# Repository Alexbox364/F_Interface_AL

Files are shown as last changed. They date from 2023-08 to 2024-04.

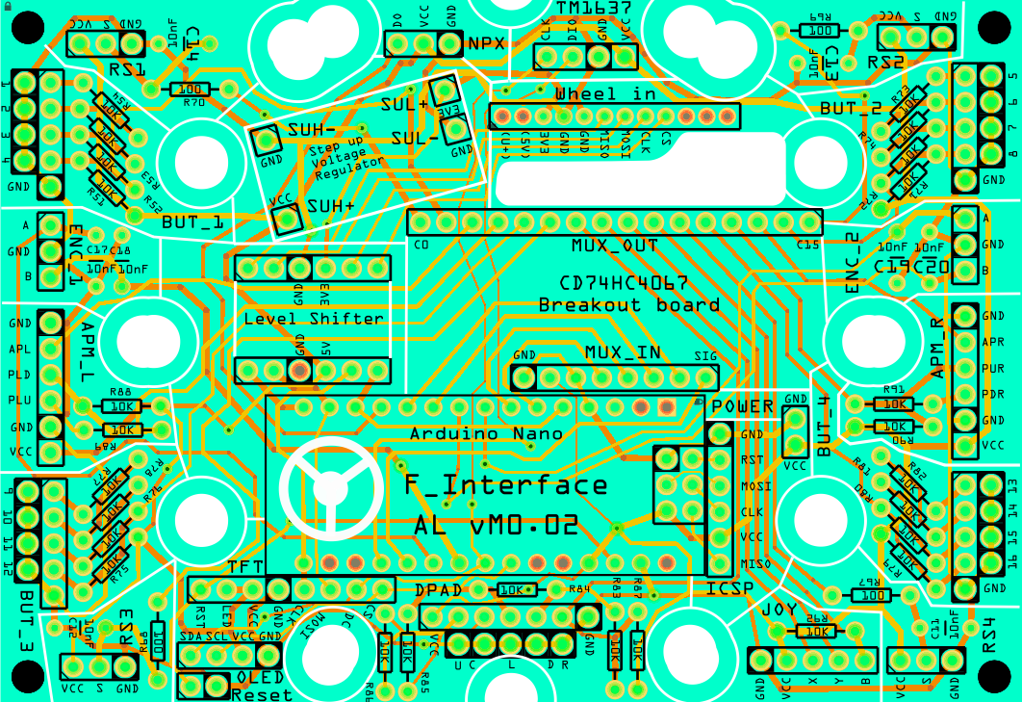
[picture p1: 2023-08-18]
F_Interface_AL_Hardware_v0.02/F_Interface_AL_Hardware_v0.02_circuit imprimé.png

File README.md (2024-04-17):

# F_Interface_AL Project v0.06
##DIY steering wheel and button bow project

You want to build your own DIY Fanatec base compatible Steering Wheel? You're at the right place :-)

Welcome to the F_interface project. 

Purpose of this project is to bring a versatile platform to build DIY steering wheels intended to work with Fanatec simracing bases. 



Fanatec ecosystem is great for simracing, but when it comes to integrate custom DIY wheel to enrich your experience, possibilities are limited. 

You can use the Podium hub to hook up a rim and few buttons but you don’t have much more possibilities. 

The F_interface offers you the opportunity to build a custom DIY wheel with a variety of combinations including :

- Up to 24 push buttons
- Up to 2 rotary encoders
- Up to 4 rotary switches
- Advance paddle modules
- TM1637 segmented displays
- OLED displays
- TFT LCD display
- Individually addressable RGB LEDs

This project brings you both a hardware and software platform to help you build your dream DIY wheel. 

It is build on using the SPI protocol from Fanatec to communicate between the wheel and the base. This way, you don’t need any cable or wireless communication between the wheel and the base, everything goes through the pins in the center of the Fanatec QR system.

This work is based on previous work from [Darknao](https://github.com/darknao/btClubSportWheel) and [Ishachar](https://github.com/lshachar/Arduino_Fanatec_Wheel) who brought public the base of the SPI communication between the Fanatec base and the wheels.

The SPI protocol is not yet fully understood. So what is currently feasible is : 
- use up to 24 buttons (including D-pad / rotary encoders / rotary switches)  
- use 2 axis for clutch / brake / acceleration
- get 9 status LEDs
- get 7 segment display information
—> tu sum it up, all features of wheels like Porsche 918 RSR, BMW GT2 v1...

What is currently not possible :
- get RGB Led information
- get enriched information displayed en latest OLED displays like lap time, tire pressure,…
- more buttons 
—> to sum it up, extended features brought by Maclaren GT3 v2 wheel, formula v2.5, Porsche endurance are not accessible yet, unless we better understand SPI protocol used by these wheels and by the data port.
BUT, there is a hope to integrate these feature via bluetooth using a Arduino nano ESP 32 and Simhub in future development to integrate TFT LCD screens, if your project really needs it. 

# The Hardware
The New F_interface is available in multiple form factors to suit your needs in terms of wheel setup. All board versions were designed using Fritzing, all source files are available in the repo. It is designed to be easily soldered by anyone using as few various components as possible and using only cheap and available components. It’s versatile, in the way you can only solder group of components that interest you for your build, especially if you want more rotary switches or more buttons,…

All details about the board can be found in the F_Interface_HW file. 

On the hardware side, you now have the choice between various versions depending on your needs. They vary in terms of sizes and inputs/output capabilities. They though all use the same base schematic to establish the link with the Fanatec base.

A presentation of the range is available below. The main hardware platform which is described if the original one beeing the FULL_NANO version. 

- A smallest form factor PCB based on an ATMEGA328P microcontroller just to unlock the force feedback for advanced users : ATMEGA328P_NO_HEADER
- A smallest form factor PCB based on an ATMEGA328P microcontroller just to unlock the force feedback + a few buttons for advanced user : ATMEGA328P_WITH_HEADER
- A small form factor PCB based on an arduino nano just to unlock the force feedback : NANO_NO_HEADER
- A small form factor PCB based on an arduino nano just to unlock the force feedback + a few buttons : NANO_WITH_HEADER
- A small form factor PCB based on an arduino PRO MICRO just to unlock the force feedback + a few buttons : PROMICRO_WITH_HEADER
- A podium hub form factor PCB based on an arduino nano with full features (buttons, rotary encoder, rotary switches) : FULL_NANO
- A podium hub form factor PCB based on an arduino PRO MICRO with full features (buttons, rotary encoder, rotary switches) : FULL_PROMICRO
- A button box wich is not intended to work with a Fanatec wheel base but which is very close in terms of I/Os.
















# Force feedback unlocker

Work from user Lele1494 is shared in the repo in the folder FFB unlocker_Lele1494.

It features a Fanatec force feedback unlocker in the shape of a small dongle. 

311509914-fe021610-d0ed-4bec-9fa5-f2b88aa8f5ab
313604595-764e521d-4c99-446e-8980-a8b3b699f9a5
313604620-f500a8e4-6ad1-47dd-8eb8-25f93431ef64

# Old presentation for legacy : F_Interface_AL Project v0.02

You want to build your own DIY Fanatec base compatible Steering Wheel? You're at the right place :-)

Welcome to the F_interface project. 

Purpose of this project is to bring a versatile platform to build DIY steering wheels intended to work with Fanatec simracing bases. 



Fanatec ecosystem is great for simracing, but when it comes to integrate custom DIY wheel to enrich your experience, possibilities are limited. 

You can use the Podium hub to hook up a rim and few buttons but you don’t have much more possibilities. 

The F_interface offers you the opportunity to build a custom DIY wheel with a variety of combinations including :

- Up to 24 push buttons
- Up to 2 rotary encoders
- Up to 4 rotary switches
- Advance paddle modules
- TM1637 segmented displays
- OLED displays
- TFT LCD display
- Individually addressable RGB LEDs

This project brings you both a hardware and software platform to help you build your dream DIY wheel. 

It is build on using the SPI protocol from Fanatec to communicate between the wheel and the base. This way, you don’t need any cable or wireless communication between the wheel and the base, everything goes through the pins in the center of the Fanatec QR system.

This work is based on previous work from [Darknao](https://github.com/darknao/btClubSportWheel) and [Ishachar](https://github.com/lshachar/Arduino_Fanatec_Wheel) who brought public the base of the SPI communication between the Fanatec base and the wheels.

The SPI protocol is not yet fully understood. So what is currently feasible is : 
- use up to 24 buttons (including D-pad / rotary encoders / rotary switches)  
- use 2 axis for clutch / brake / acceleration
- get 9 status LEDs
- get 7 segment display information
—> tu sum it up, all features of wheels like Porsche 918 RSR, BMW GT2 v1...

What is currently not possible :
- get RGB Led information
- get enriched information displayed en latest OLED displays like lap time, tire pressure,…
- more buttons 
—> to sum it up, extended features brought by Maclaren GT3 v2 wheel, formula v2.5, Porsche endurance are not accessible yet, unless we better understand SPI protocol used by these wheels and by the data port.
BUT, there is a hope to integrate these feature via bluetooth using a Arduino nano ESP 32 and Simhub in future development to integrate TFT LCD screens, if your project really needs it. 

# The Hardware
The F_interface hardware was designed using Fritzing, all source files are available in the repo. It is designed to be easily soldered by anyone using as few various components as possible and using only cheap and available components. It’s versatile, in the way you can only solder group of components that interest you for your build, especially if you want more rotary switches or more buttons,…

All details about the board can be found in the F_Interface_vM file. 



Example of assembled PCB
AUDI_DTM_AL1

Example of integration in a DIY steering wheel
AUDI_DTM_AL6

## Dimensions 


## BOM
Bill of Material will vary depending on you project but the full list is here :
- 1 arduino nano (Approx. 3€)
- 1 PCB (Approx. 10€ if ordered by 5 on JLCPCB)
- 1 CD74HC4067 - 16 channel multiplexer (Approx. 0,5€)
- 1 Step up voltage regulator (Approx. 2€)
- 1 Level shifter (Approx 2€)
- Depending on you build, some buttons, encoder, rotary switches,…
- Some 2,54 and 2mm pitch, straight or elbowed pin arrays to hook up your buttons, switches,…
- Up to 4x 100 Ohms Resistors for Rotary switches
- Up to 26x 10k Ohms Resitors for buttons
- Up to 8x 10 or 47 nF Capacitors for inputs debounce

# The Software
The F_interface software was designed based on Darknao and Ishachar previous work. 
It handles SPI communication with the base to respect the Fanatec data structure.

It has been build in a versatile way in order to configure your wheel with the input / output you want on your wheel. 
see config_wheel.h to active / deactivate via #define //#define the various options

# More details




Abbreviations are used on the PCB and in the software to refer to input types :

APM	Advance Paddle Module
RS	Rotary switch
BUT	Button group
ENC 	Encoder
JOY	Joystick
DPAD	Group of 5 buttons that make a direction pad – up / down / left / right / center


General schematic will help you understand the PCB wiring and link with the code.
It can be found in the Fritzing file

F_Interface_AL_Hardware_v0 02_bb

## Arduino Nano
The setup uses a classic arduino nano, original or clone.
As the wheels run on 3,3v for SPI communication while arduino runs at 5V, some adaptations are necessary like a level shifter and a step up voltage regulator. 

As the base requires a fast response from arduino on SPI communication port at startup, the arduino bootloader has to be removed. Arduino will then be programmed via ICSP port. See this page for further details : [Arduino as ISP](https://docs.arduino.cc/built-in-examples/arduino-isp/ArduinoISP)

## Step up voltage regulator


## Level shifter


## Wheel input


## CD74HC4067 multiplexer


## Rotary switch


## Encoder


## Button groups


## APM
I advise you used the fantastic design from [Stuyo] (https://diy-sim.com/sim-projects/sim-gear/item/dual-paddle-shifter-clutch-module-v15-


## DPAD


## Joystick


## TM1637


## OLED display


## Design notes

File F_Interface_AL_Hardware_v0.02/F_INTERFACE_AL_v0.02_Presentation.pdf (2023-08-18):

# F_Interface_AL v0.02 presentation

# Global interfacing view

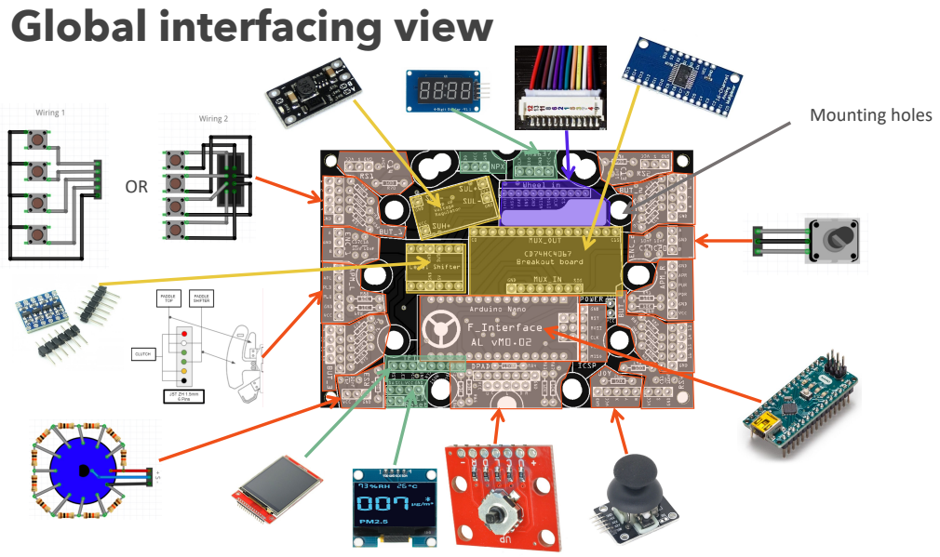
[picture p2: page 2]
Mounting holes

# BOM

- 1 arduino nano (Approx. 3€)
- 1 PCB (Approx. 5-7€ if ordered by 5 on JLCPCB)
- 1 CD74HC4067 - 16 channel multiplexer (Approx. 0,5€)
- 1 Step up voltage regulator (Approx. 2€)
- 1 Level shifter (Approx 2€)
- Depending on you build, some buttons, encoder, rotary switches,…
- Some 2,54 and 2mm pitch, straight or elbowed pin arrays to hook up your buttons, switches,…
- Up to 4x 100 Ohms Resistors for Rotary switches
- Up to 26x 10k Ohms Resitors for buttons
- Up to 8x 10 or 47 nF Capacitors for inputs debounce

I advise to take 1/6W or 1/8W resistors as they are much smaller. 1 or 1/2W resistors are too big to fit on the PCB

# Dimensions

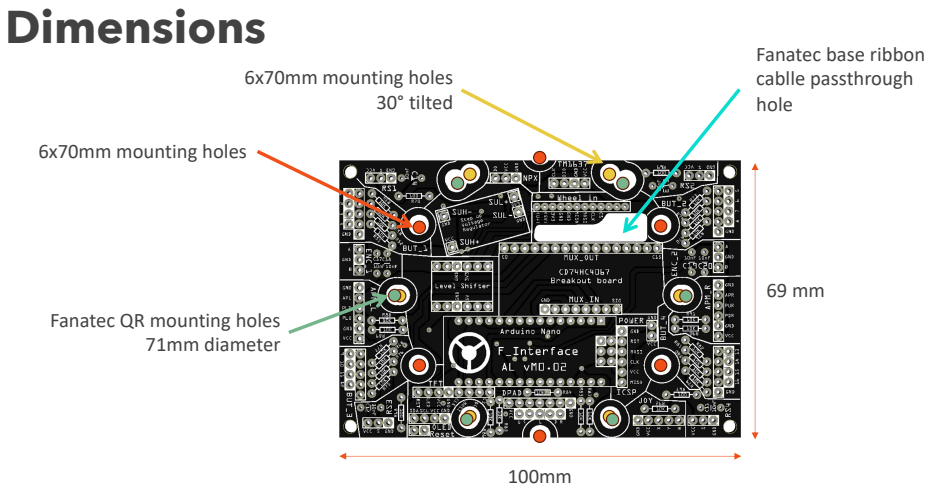
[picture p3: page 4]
6x70mm mounting holes; 6x70mm mounting holes 30° tilted; 71mm diameter

Fanatec base ribbon
cablle passthrough
hole

Fanatec QR mounting holes

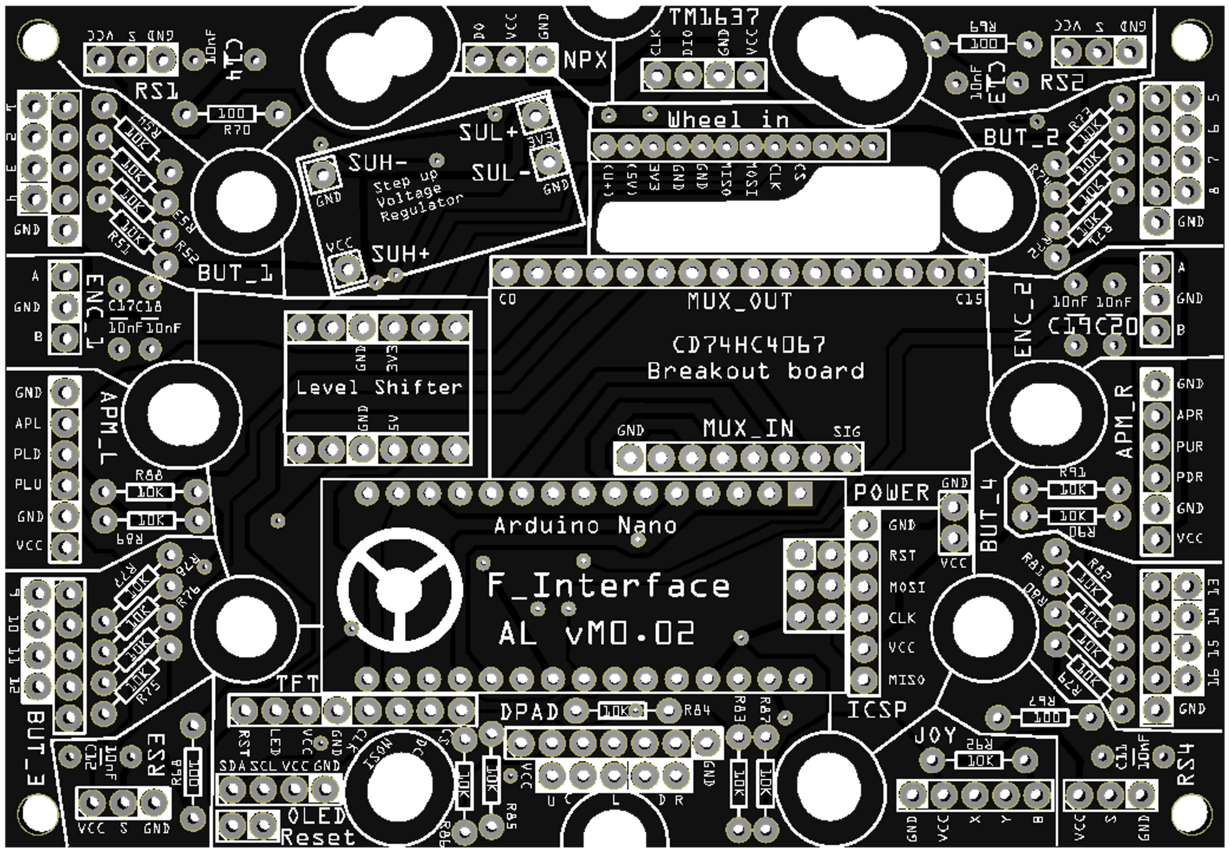
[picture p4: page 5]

# Abbreviations

Abbreviations are used on the PCB and in the software to refer to input types :

APM | Advance Paddle Module
RS | Rotary switch
BUT | Button group
ENC | Encoder
JOY | Joystick
DPAD | Group of 5 buttons that make a direction pad – up / down / left / right / center

# General schematic

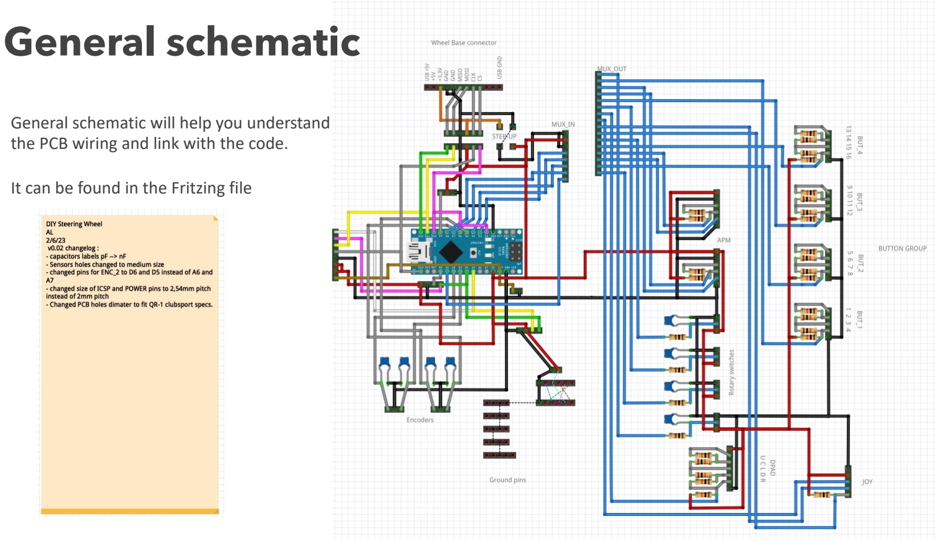
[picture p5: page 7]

General schematic will help you understand the PCB wiring and link with the code.

It can be found in the Fritzing file

# Arduino nano

The setup uses a classic arduino nano, original or clone.
As the wheels run on 3,3v for SPI communication while arduino runs at 5V, some adaptations are necessary like a level shifter and a step up voltage regulator.

As the base requires a fast response from arduino on SPI communication port at startup, the arduino bootloader has to be removed. Arduino will then be programmed via ICSP port. See this page (https://docs.arduino.cc/built-in-examples/arduino-isp/ArduinoISP) for further details

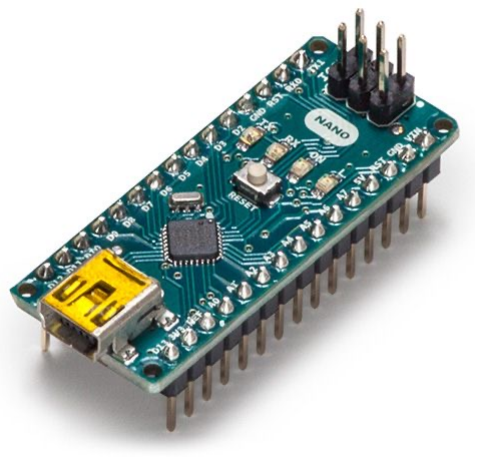
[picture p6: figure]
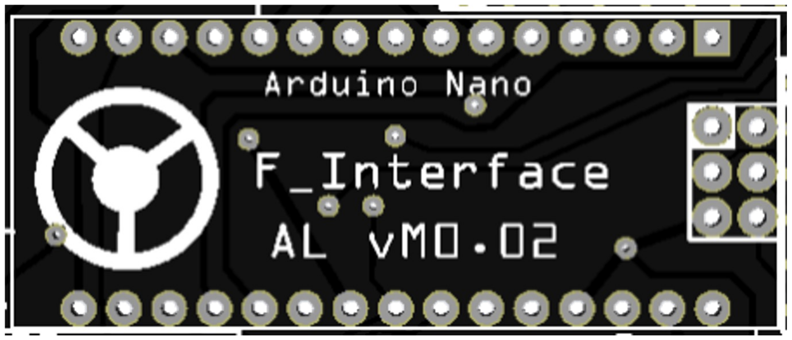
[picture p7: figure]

# Step up voltage regulator

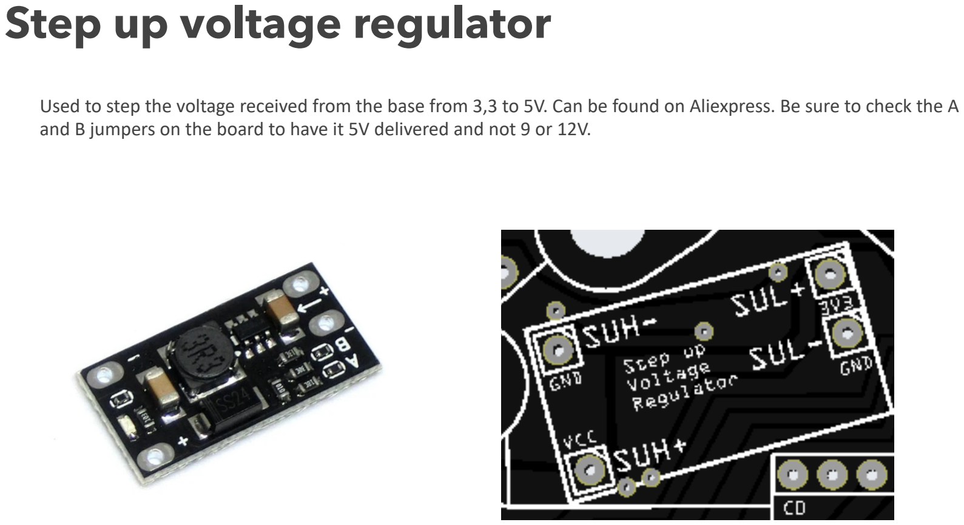
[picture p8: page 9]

Used to step the voltage received from the base from 3,3 to 5V. Can be found on Aliexpress. Be sure to check the A and B jumpers on the board to have it 5V delivered and not 9 or 12V.

# Level shifter

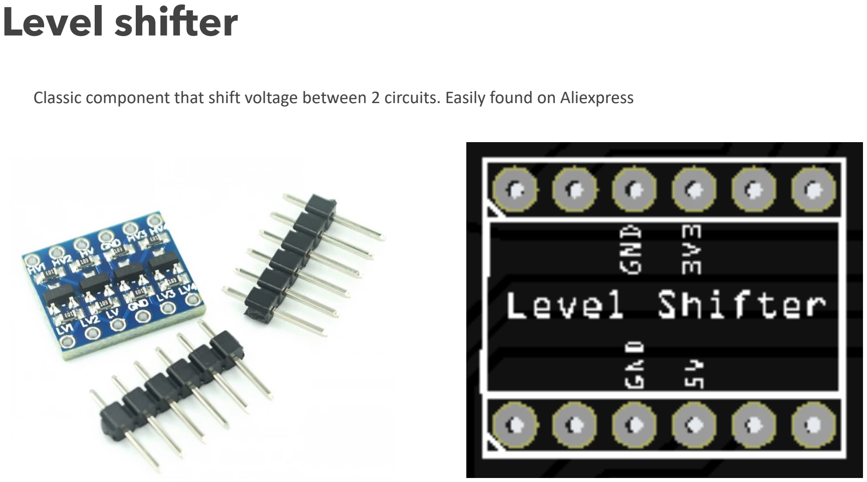
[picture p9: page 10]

Classic component that shift voltage between 2 circuits. Easily found on Aliexpress

# Wheel input

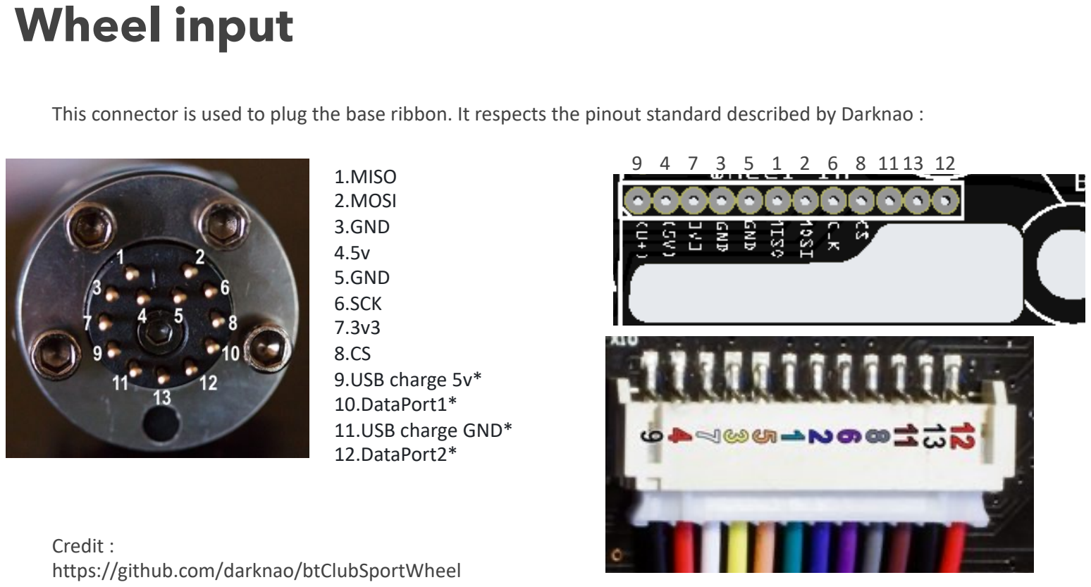
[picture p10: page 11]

This connector is used to plug the base ribbon. It respects the pinout standard described by Darknao :

1.MISO
2.MOSI
3.GND
4.5v
5.GND
6.SCK
7.3v3
8.CS
9.USB charge 5v*
10.DataPort1*
11.USB charge GND*
12.DataPort2*

9 4 7 3 5 1 2 6 8 11 13 12

Credit :
https://github.com/darknao/btClubSportWheel

# CD74HC4067 multiplexer

This component is used to multiplexed the analog reading from buttons / rotary switches / … to the arduino.

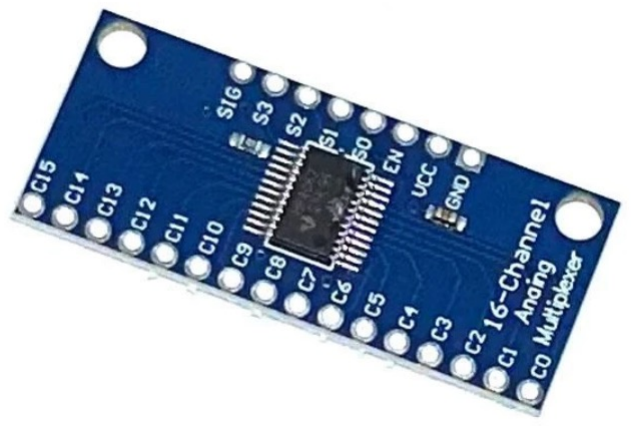
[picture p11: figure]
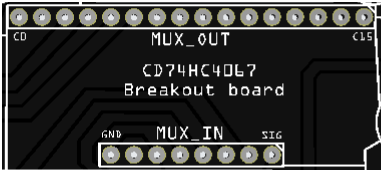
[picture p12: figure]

# Rotary switch

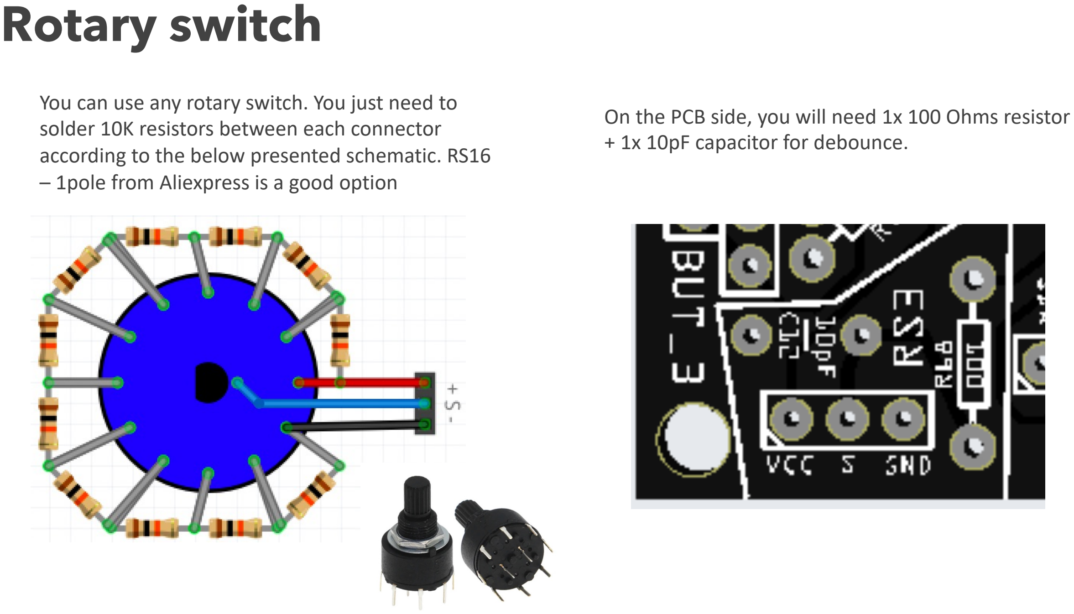
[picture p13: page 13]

You can use any rotary switch. You just need to solder 10K resistors between each connector according to the below presented schematic. RS16 – 1pole from Aliexpress is a good option

On the PCB side, you will need 1x 100 Ohms resistor + 1x 10pF capacitor for debounce.

# Encoder

Everything needed for the encoder is placed on the PCB.

On the PCB side, you will need 2x 10pF capacitors for debounce.

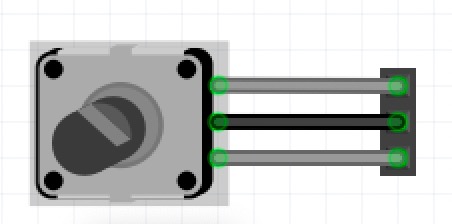
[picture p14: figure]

# Button groups

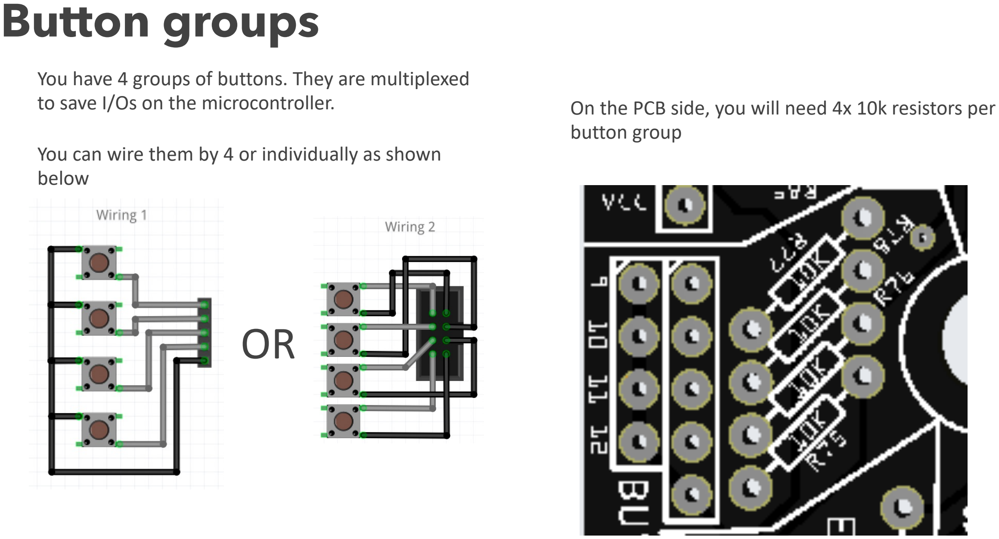
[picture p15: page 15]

You have 4 groups of buttons. They are multiplexed to save I/Os on the microcontroller.

You can wire them by 4 or individually as shown below

On the PCB side, you will need 4x 10k resistors per button group

OR

# APM

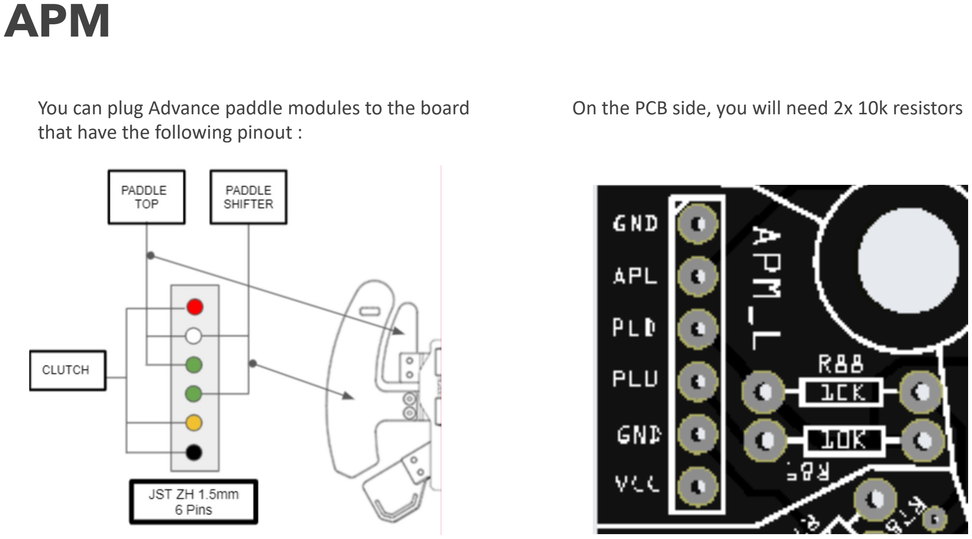
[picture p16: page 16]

You can plug Advance paddle modules to the board that have the following pinout :

On the PCB side, you will need 2x 10k resistors

# DPAD

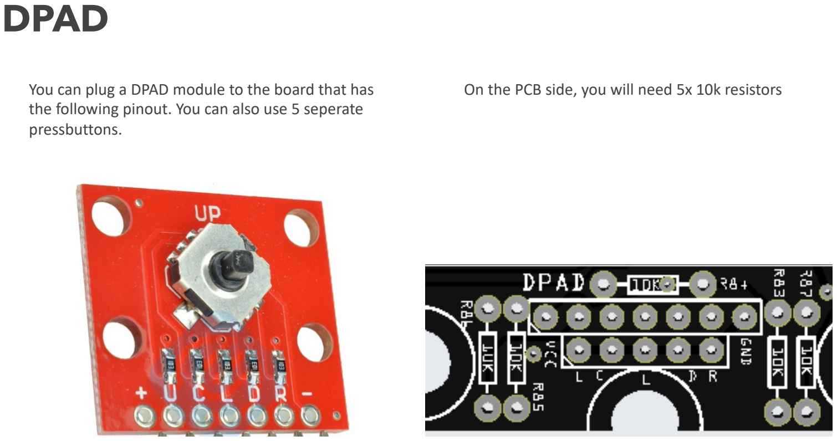
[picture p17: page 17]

You can plug a DPAD module to the board that has the following pinout. You can also use 5 seperate pressbuttons.

On the PCB side, you will need 5x 10k resistors

# Joystick

You can plug a joystick module to the board, a standard one or custom 1.

On the PCB side, you will need 1x 10k resistors to manage the button press

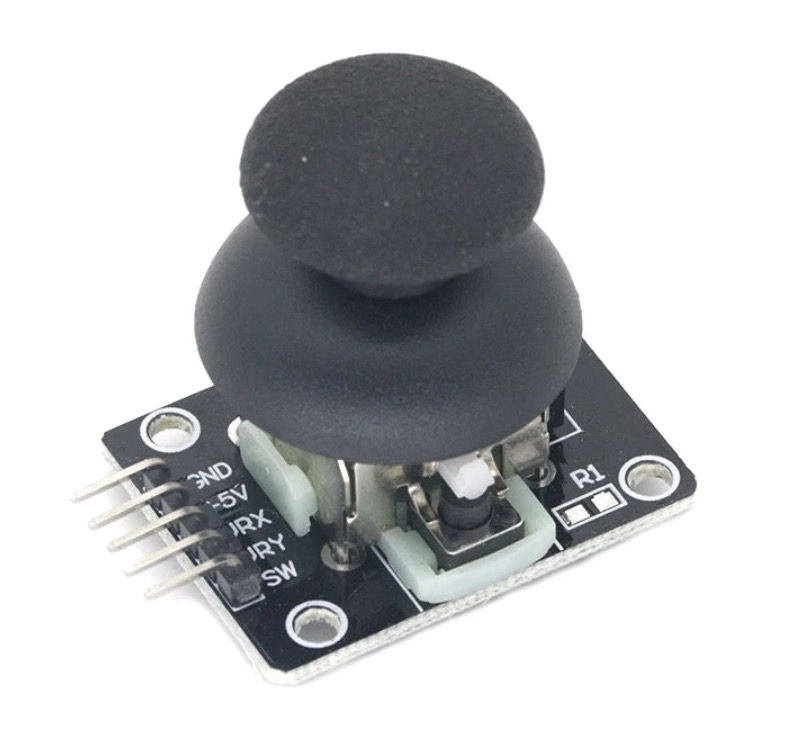
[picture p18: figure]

TM1637

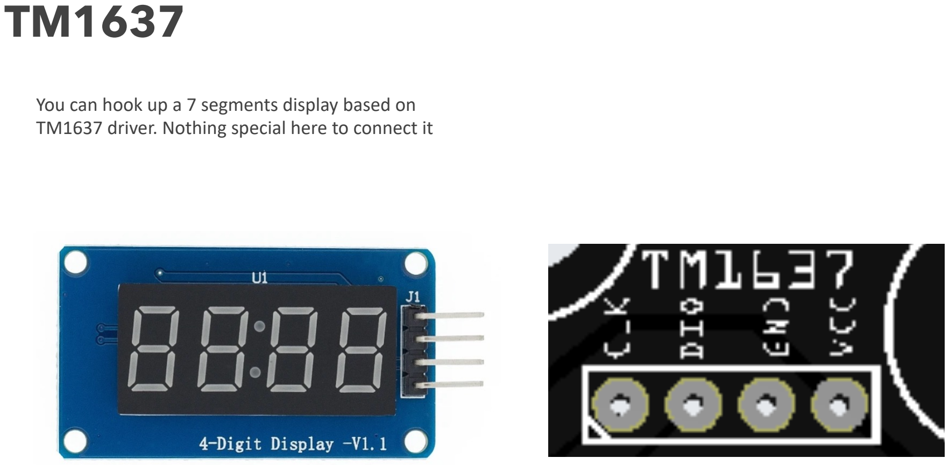
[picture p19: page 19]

You can hook up a 7 segments display based on TM1637 driver. Nothing special here to connect it

# OLED display

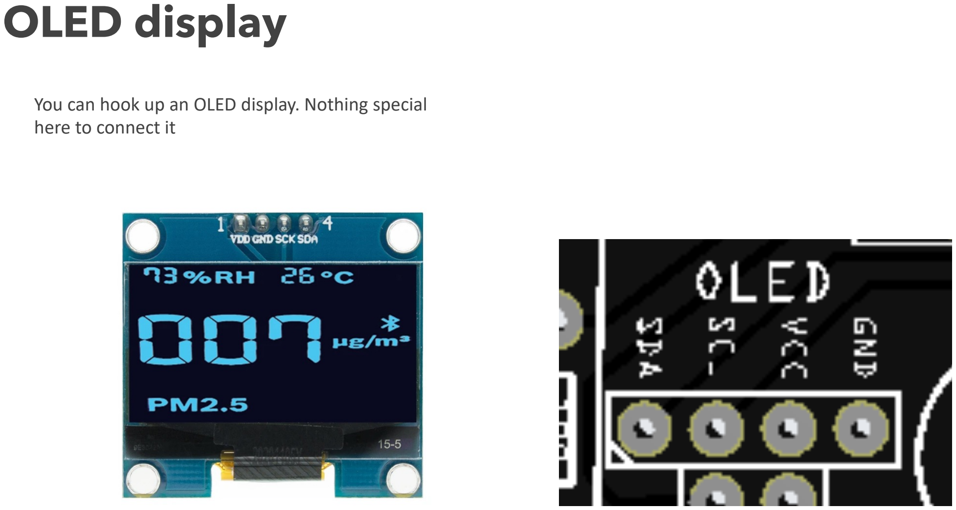
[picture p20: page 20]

You can hook up an OLED display. Nothing special here to connect it

# TFT LCD Display

You can hook up an TFT LCD display based on ST7735 or other SPI based LCD TFT driver.

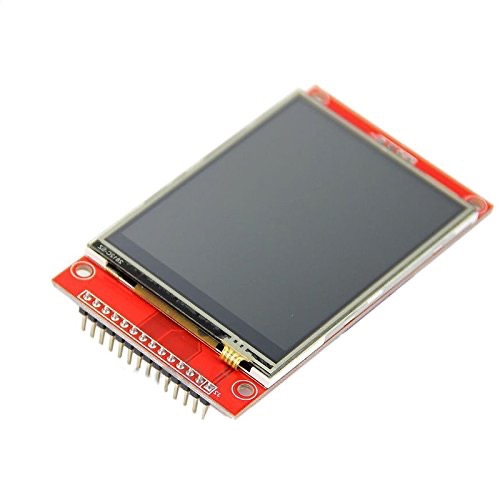
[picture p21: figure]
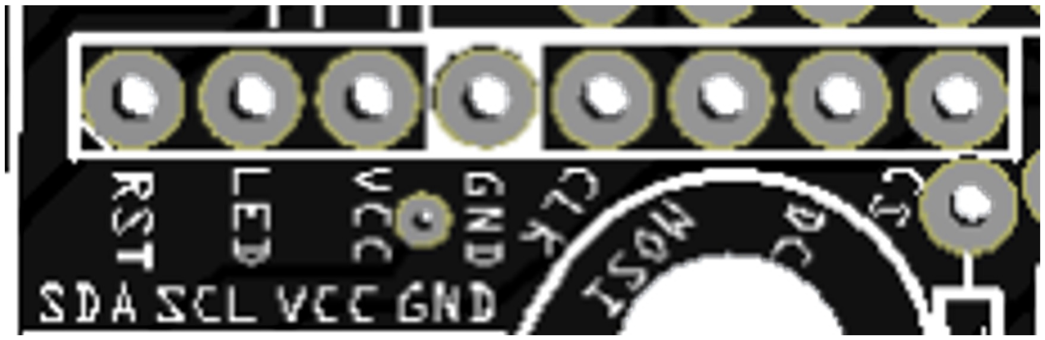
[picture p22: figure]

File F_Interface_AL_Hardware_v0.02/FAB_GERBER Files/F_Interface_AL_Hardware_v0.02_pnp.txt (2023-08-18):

*Pick And Place List
*Company=
*Author=
*eMail=
*
*Project=F_Interface_AL_Hardware_v0.02
*Date=11:37:08
*CreatedBy=Fritzing 0.9.3b.04.19.5c895d327c44a3114e5fcc9d8260daf0cbb52806
*
*
*Coordinates in mm, always center of component
*Origin 0/0=Lower left corner of PCB
*Rotation in degree (0-360, math. pos.)
*
*No;Value;Package;X;Y;Rotation;Side;Name
1;;;97.2606;-51.1843;0;Bottom;TXT41
2;;;97.3036;-2.7086;0;Bottom;Hole6
3;;;63.0287;-54.969;90;Bottom;TXT41
4;;;43.6511;-19.5718;0;Bottom;Via23
5;;;96.9908;-18.9012;0;Bottom;IMG2
6;;;28.406;-17.9488;0;Bottom;Via12
7;;THT;49.9097;-8.54815;-90;Bottom;DPAD
8;;;99.2048;-13.9311;-90;Bottom;TXT41
9;;;88.9429;-56.0134;-45;Bottom;TXT41
10;;;89.0626;-58.631;-45;Bottom;TXT41
11;;;18.5424;-60.0351;0;Bottom;TXT41
12;;;96.991;-61.4854;0;Bottom;IMG2
13;;;97.1663;-32.7144;0;Bottom;TXT41
14;;;32.8843;-54.5547;-15;Bottom;TXT42
15;;;94.4382;-11.2655;0;Bottom;IMG2
16;;;7.83363;-66.7065;180;Bottom;TXT41
17;10k;THT;88.8945;-13.9753;-135;Bottom;R79
18;;;33.1615;-53.3417;-15;Bottom;TXT42
19;;;29.2762;-42.6549;0;Bottom;IMG2
20;;;97.1976;-27.6657;0;Bottom;TXT41
21;;;79.7563;-62.7303;-90;Bottom;TXT41
22;10k;THT;10.4626;-53.0371;45;Bottom;R52
23;;;51.6825;-11.2254;0;Bottom;Via5
24;;;47.4307;-23.5088;0;Bottom;Via22
25;;cap-pth-5mm;87.7786;-43.7062;90;Bottom;C19
26;;THT;94.4461;-44.9362;0;Bottom;ENC_2
27;;THT;30.5701;-42.6641;-90;Bottom;J15
28;;;2.34541;-55.7312;0;Bottom;IMG2
29;;;2.37106;-58.2712;0;Bottom;IMG2
30;;THT;9.67356;-3.66119;-90;Bottom;RS3
31;;;11.9102;-28.9956;0;Bottom;TXT41
32;;;2.68856;-66.2087;0;Bottom;Hole3
33;;;2.68856;-2.7086;0;Bottom;Hole5
34;;;16.341;-23.0288;0;Bottom;Via19
35;;THT;70.4227;-20.095;0;Bottom;J14
36;;cap-pth-5mm;7.80857;-7.47118;180;Bottom;C12
37;;;99.2359;-58.9297;-90;Bottom;TXT41
38;;THT;4.91106;-30.9662;0;Bottom;APM_L
39;;;0.39553;-53.2226;90;Bottom;TXT41
40;;;96.4137;-42.31;0;Bottom;TXT41
41;;;39.201;-23.3463;0;Bottom;Via1
42;;;29.4653;-35.1714;-90;Bottom;TXT41
43;;;52.4655;-5.85922;-90;Bottom;IMG2
44;;;42.5955;-5.86011;90;Bottom;TXT41
45;;;51.3018;-34.0561;0;Bottom;TXT41
46;;;35.391;-56.3662;0;Bottom;Via9
47;;THT;79.5236;-4.29619;-90;Bottom;JOY
48;;;70.418;-26.4742;0;Bottom;IMG2
49;;;12.7302;-66.7065;180;Bottom;TXT41
50;;THT;2.68856;-16.9962;0;Bottom;J12
51;;THT;4.91106;-44.3012;0;Bottom;ENC_1
52;;;12.4391;-1.40664;0;Bottom;TXT41
53;;;53.1098;-54.9727;90;Bottom;TXT41
54;;;77.868;-29.7635;0;Bottom;TXT41
55;;;4.8797;-27.1327;0;Bottom;IMG2
56;;;2.66611;-20.814;0;Bottom;IMG2
57;;;7.05563;-1.41906;0;Bottom;TXT41
58;;;34.2555;-52.3587;-15;Bottom;TXT42
59;;;1.9007;-34.6273;0;Bottom;TXT41
60;;THT;41.4236;-64.6212;-90;Bottom;NPX
61;;;22.3524;-26.8317;0;Bottom;Via18
62;;;87.3622;-44.6187;0;Bottom;TXT41
63;10k;THT;10.7895;-21.2871;135;Bottom;R77
64;;;1.93206;-37.1672;0;Bottom;TXT41
65;10k;THT;10.472;-55.5678;-135;Bottom;R53
66;10k;THT;10.7801;-16.1978;-45;Bottom;R76
67;;;49.3136;-54.665;90;Bottom;TXT41
68;;;50.0784;-3.78267;0;Bottom;TXT41
69;;cap-pth-5mm;90.9536;-43.7062;90;Bottom;C20
70;;;93.1839;-4.30403;0;Bottom;IMG2
71;;;10.3086;-52.9442;45;Bottom;TXT41
72;;;45.2169;-54.0237;-15;Bottom;TXT41
73;;;1.86935;-29.6413;0;Bottom;TXT41
74;;;0.364147;-55.6999;90;Bottom;TXT41
75;;;97.3545;-11.2341;0;Bottom;TXT41
76;;;32.0206;-34.7834;-90;Bottom;TXT41
77;;THT;26.0134;-55.1622;75;Bottom;SUH-
78;10k;THT;87.4611;-29.3787;0;Bottom;R91
79;10k;THT;50.6107;-11.2253;0;Bottom;R84
80;;;37.4732;-5.12887;90;Bottom;TXT41
81;;;2.66611;-18.274;0;Bottom;IMG2
82;;;48.4935;-17.2491;0;Bottom;TXT42
83;;;30.7103;-37.552;0;Bottom;TXT42
84;;;97.1663;-30.2057;0;Bottom;TXT41
85;;;57.5846;-6.06021;90;Bottom;TXT41
86;;;30.4228;-46.3434;0;Bottom;Via17
87;;;47.3855;-5.88462;-90;Bottom;IMG2
88;;;99.2675;-53.8497;-90;Bottom;TXT41
89;;;87.5465;-27.0505;0;Bottom;TXT41
90;;;9.90714;-42.4761;0;Bottom;TXT41
91;;;13.0091;-42.4291;0;Bottom;TXT41
92;;;99.2045;-21.3315;-90;Bottom;TXT41
93;;;9.72226;-1.46563;0;Bottom;TXT41
94;;;92.2118;-65.264;0;Bottom;IMG2
95;;;36.0025;-9.16448;116;Bottom;TXT41
96;10k;THT;88.8945;-51.1321;135;Bottom;R71
97;;;74.4318;-4.30403;0;Bottom;IMG2
98;;;74.4945;-1.51329;-90;Bottom;TXT41
99;;;96.9654;-53.8654;0;Bottom;IMG2
100;;THT;4.91106;-55.7312;0;Bottom;BUT_1
101;;;27.4653;-49.2119;-15;Bottom;TXT41
102;;;97.1663;-44.8813;0;Bottom;TXT41
103;;;77.066;-1.54462;-90;Bottom;TXT41
104;;;49.9255;-5.88462;-90;Bottom;IMG2
105;;;93.4974;-7.84131;-90;Bottom;TXT41
106;;;22.0325;-8.60002;90;Bottom;TXT41
107;;;26.4065;-6.53812;0;Bottom;TXT41
108;;;10.706;-58.0619;45;Bottom;TXT41
109;;;79.9759;-6.96332;0;Bottom;TXT41
110;;;88.9782;-51.004;-45;Bottom;TXT41
111;;;21.1624;-1.81107;0;Bottom;IMG2
112;;;8.54235;-6.89109;90;Bottom;TXT41
113;;;30.4388;-7.77698;131;Bottom;TXT41
114;;cap-pth-5mm;9.35606;-43.3887;90;Bottom;C17
115;;;79.6685;-2.29716;-90;Bottom;TXT41
116;;;80.2553;-65.7783;0;Bottom;TXT41
117;;;26.2188;-4.75872;0;Bottom;IMG2
118;;;94.4382;-44.944;0;Bottom;IMG2
119;;;88.9076;-18.8305;45;Bottom;TXT41
120;;THT;60.1561;-47.1587;90;Bottom;MUX_OUT
121;;cap-pth-5mm;11.8961;-43.3887;90;Bottom;C18
122;;;0.364118;-58.2712;90;Bottom;TXT41
123;;;2.37106;-60.8112;0;Bottom;IMG2
124;;THT;30.5701;-32.6426;-90;Bottom;J16
125;;;28.7588;-8.8352;124;Bottom;TXT41
126;;;53.8704;-3.77957;0;Bottom;TXT41
127;;;87.122;-67.5369;180;Bottom;TXT41
128;;;27.2066;-11.2342;0;Bottom;IMG2
129;;;94.4382;-37.9512;0;Bottom;IMG2
130;;;96.4766;-47.4527;0;Bottom;TXT41
131;;THT;57.2986;-63.3512;-90;Bottom;TM1637
132;;;63.966;-10.6463;0;Bottom;Via13
133;;;99.2049;-56.3897;-90;Bottom;TXT41
134;;;90.9393;-44.5481;0;Bottom;TXT41
135;;;10.9538;-21.2861;-45;Bottom;TXT41
136;;;12.1861;-3.64551;0;Bottom;IMG2
137;;;4.91106;-37.324;0;Bottom;IMG2
138;10k;THT;88.8945;-53.6721;135;Bottom;R72
139;;;88.8371;-16.4316;45;Bottom;TXT41
140;;;97.1663;-35.3171;0;Bottom;TXT41
141;;;51.2426;-54.7513;90;Bottom;TXT41
142;10k;THT;87.4611;-27.1562;180;Bottom;R90
143;;;62.2396;-5.32643;90;Bottom;TXT41
144;10k;THT;88.8852;-56.2028;-45;Bottom;R74
145;;;94.4696;-51.2784;0;Bottom;IMG2
146;;;85.4148;-10.5123;0;Bottom;TXT41
147;;;77.7729;-23.1971;0;Bottom;TXT41
148;;cap-pth-5mm;92.501;-7.4712;0;Bottom;C11
149;;;53.5042;-66.0016;-90;Bottom;TXT41
150;;;58.9989;-54.8594;90;Bottom;TXT41
151;;THT;44.596;-56.2646;75;Bottom;SUL-
152;;;93.5336;-1.57598;-90;Bottom;TXT41
153;;;58.5646;-63.3512;0;Bottom;IMG2
154;;;0.615008;-13.2723;90;Bottom;TXT41
155;;;2.47145;-46.744;0;Bottom;TXT41
156;;;49.5135;-21.1875;0;Bottom;TXT42
157;;;41.4235;-5.88379;0;Bottom;Via20
158;;;29.2762;-32.6517;0;Bottom;IMG2
159;;;57.0233;-55.0256;90;Bottom;TXT41
160;;;73.5266;-16.2414;0;Bottom;TXT41
161;;THT;89.6836;-65.2562;-90;Bottom;RS2
162;;;99.2048;-16.2826;-90;Bottom;TXT41
163;;;41.628;-67.3285;-90;Bottom;TXT41
164;;;0.583653;-15.7183;90;Bottom;TXT41
165;100;THT;85.2386;-10.6462;180;Bottom;R67
166;;THT;19.8818;-1.77651;-90;Bottom;Reset
167;;;1.99477;-24.5927;0;Bottom;TXT41
168;;THT;60.1442;-31.9422;90;Bottom;MUX_IN
169;;;2.64046;-13.194;0;Bottom;IMG2
170;;;11.0141;-18.7599;-45;Bottom;TXT41
171;;THT;5.22856;-15.7262;0;Bottom;BUT_3
172;;;61.0701;-54.8222;90;Bottom;TXT41
173;;;49.4778;-60.0441;0;Bottom;Via14
174;;;44.8017;-3.65962;0;Bottom;TXT41
175;;;97.3036;-66.2087;0;Bottom;Hole4
176;;THT;94.4461;-16.3612;0;Bottom;BUT_4
177;;;73.583;-26.2832;0;Bottom;TXT41
178;;cap-pth-5mm;80.5159;-62.7162;180;Bottom;C13
179;;;24.6196;-8.64705;90;Bottom;TXT41
180;;THT;10.3086;-64.6212;-90;Bottom;RS1
181;;;47.4476;-21.4412;90;Bottom;Arduino Nano
182;;;61.5627;-38.8787;0;Bottom;TXT42
183;;;10.9788;-16.1494;-45;Bottom;TXT41
184;;;57.5298;-8.53736;-90;Bottom;IMG2
185;;;2.34541;-53.1912;0;Bottom;IMG2
186;10k;THT;60.1561;-5.24869;90;Bottom;R83
187;;;1.83799;-32.1187;0;Bottom;TXT41
188;;;65.2125;-24.0282;0;Bottom;IMG2
189;;THT;2.37106;-57.0012;0;Bottom;J13
190;;;84.8426;-2.26555;-90;Bottom;TXT41
191;;;89.1709;-53.6733;-45;Bottom;TXT41
192;;;18.6424;-6.53812;0;Bottom;TXT41
193;;;96.991;-58.9454;0;Bottom;IMG2
194;;THT;28.5026;-11.2253;-90;Bottom;TFT
195;;THT;94.4461;-56.3662;0;Bottom;BUT_2
196;;;96.9654;-13.8212;0;Bottom;IMG2
197;;;43.9832;-64.6055;0;Bottom;IMG2
198;;;73.9561;-13.5928;0;Bottom;TXT41
199;;;31.8889;-40.0717;-90;Bottom;TXT41
200;10k;THT;39.8716;-5.52555;90;Bottom;R85
201;;THT;22.4218;-4.76863;-90;Bottom;OLED
202;10k;THT;11.9672;-26.8158;180;Bottom;R89
203;;;90.8054;-2.29722;-90;Bottom;TXT41
204;;;55.2775;-3.71071;0;Bottom;TXT41
205;;;10.4144;-55.449;45;Bottom;TXT41
206;10k;THT;88.8852;-58.7428;-45;Bottom;R73
207;;;19.4455;-8.50622;90;Bottom;TXT41
208;;;44.277;-67.3335;-90;Bottom;TXT41
209;;;0.646363;-20.8926;90;Bottom;TXT41
210;;;97.1976;-37.8885;0;Bottom;TXT41
211;;;10.9788;-13.6094;-45;Bottom;TXT41
212;;;25.8559;-8.54815;0;Bottom;Via24
213;;;1.78423;-44.1601;0;Bottom;TXT41
214;;;33.8631;-8.2705;110;Bottom;TXT41
215;;;51.2269;-31.9618;0;Bottom;IMG2
216;100;THT;18.5636;-60.1762;0;Bottom;R70
217;;;2.64046;-15.734;0;Bottom;IMG2
218;;;51.901;-25.2513;0;Bottom;Via3
219;10k;THT;10.7895;-58.1078;-135;Bottom;R54
220;;THT;43.4937;-60.0441;75;Bottom;SUL+
221;;;99.2359;-61.4384;-90;Bottom;TXT41
222;10k;THT;88.8945;-16.5153;-135;Bottom;R80
223;;;50.0705;-11.0341;0;Bottom;TXT41
224;;;46.1736;-3.87129;0;Bottom;TXT41
225;;THT;66.4756;-21.4818;0;Bottom;ICSP
226;;;55.0644;-54.924;90;Bottom;TXT41
227;;;15.3209;-6.0952;90;Bottom;TXT41
228;;;44.8298;-5.87193;-90;Bottom;IMG2
229;;;1.77524;-50.5258;0;Bottom;TXT41
230;;;96.9654;-16.3612;0;Bottom;IMG2
231;;;73.6019;-23.7875;0;Bottom;TXT41
232;10k;THT;11.8707;-29.178;0;Bottom;R88
233;;;82.2399;-2.29691;-90;Bottom;TXT41
234;;;12.876;-64.6055;0;Bottom;IMG2
235;;;69.0319;-33.9435;0;Bottom;TXT41
236;;;0.552299;-18.321;90;Bottom;TXT41
237;10k;THT;88.8852;-21.6046;45;Bottom;R82
238;;THT;90.6361;-4.29619;-90;Bottom;RS4
239;;;46.1708;-19.5718;0;Bottom;Via7
240;;THT;60.147;-57.5244;-90;Bottom;Wheel in
241;;;97.1663;-25.2197;0;Bottom;TXT41
242;;;89.741;-67.3976;180;Bottom;TXT41
243;;;31.9976;-46.9733;0;Bottom;Via16
244;;;4.8797;-50.6198;0;Bottom;IMG2
245;10k;THT;10.7801;-13.6578;-45;Bottom;R75
246;;;94.4382;-27.8225;0;Bottom;IMG2
247;;;41.1797;-44.8374;0;Bottom;TXT41
248;;;96.9908;-21.4412;0;Bottom;IMG2
249;;;84.6035;-59.5412;0;Bottom;Via8
250;10k;THT;10.7895;-18.7471;135;Bottom;R78
251;;;61.35;-66.0367;-90;Bottom;TXT41
252;;;59.0603;-66.0206;-90;Bottom;TXT41
253;;;2.73393;-41.741;0;Bottom;TXT41
254;;;23.7972;-6.5082;0;Bottom;TXT41
255;;;65.0317;-55.3825;90;Bottom;TXT41
256;;;29.3045;-40.0961;-90;Bottom;TXT41
257;10k;THT;88.8852;-19.0646;45;Bottom;R81
258;;;56.1142;-65.9664;-90;Bottom;TXT41
259;100;THT;80.1586;-65.8912;180;Bottom;R69
260;;;40.1535;-60.1762;0;Bottom;Via10
261;;;4.91106;-44.2855;0;Bottom;IMG2
262;;THT;49.93;-5.87099;-90;Bottom;J11
263;;;52.8535;-60.1762;0;Bottom;Via15
264;;;10.3438;-50.3337;45;Bottom;TXT41
265;;THT;96.9861;-17.6312;0;Bottom;J10
266;;THT;96.9861;-57.6362;0;Bottom;J9
267;;;17.0008;-65.7081;-90;Bottom;TXT41
268;;;25.8559;-57.6819;0;Bottom;Via21
269;;;87.5747;-29.2307;0;Bottom;TXT41
270;;;27.0655;-8.55304;90;Bottom;TXT41
271;10k;THT;37.6669;-5.05311;90;Bottom;R86
272;;;21.1929;-6.52833;0;Bottom;TXT41
273;;THT;77.8243;-26.6482;0;Bottom;POWER
274;;cap-pth-5mm;17.9686;-64.6212;180;Bottom;C14
275;;;60.3439;-17.2096;0;Bottom;Via11
276;;;2.08886;-26.976;0;Bottom;TXT41
277;;;88.696;-13.9974;45;Bottom;TXT41
278;;;0.364147;-60.6858;90;Bottom;TXT41
279;;;96.9654;-56.4054;0;Bottom;IMG2
280;;;88.7945;-21.4978;45;Bottom;TXT41
281;;;92.5156;-67.4603;180;Bottom;TXT41
282;10k;THT;79.8411;-7.15369;180;Bottom;R92
283;;;55.0055;-5.85922;-90;Bottom;IMG2
284;;;39.7908;-5.60865;90;Bottom;TXT41
285;;;73.9939;-21.182;0;Bottom;TXT41
286;10k;THT;62.3786;-5.24869;90;Bottom;R87
287;;;73.5669;-18.6643;0;Bottom;TXT41
288;;THT;94.4461;-31.6012;0;Bottom;APM_R
289;;;88.2653;-1.6386;-90;Bottom;TXT41
290;;;60.993;-41.0052;0;Bottom;TXT42
291;;;10.3923;-66.66;180;Bottom;TXT41
292;;;79.0226;-44.8373;0;Bottom;TXT41
293;;;60.0507;-5.24487;90;Bottom;TXT41
294;;;38.9936;-66.905;-90;Bottom;TXT41
295;;THT;28.0606;-47.4457;75;Bottom;SUH+
296;;;99.2359;-18.9482;-90;Bottom;TXT41
297;;;11.9666;-26.7;0;Bottom;TXT41
298;10k;THT;10.4626;-50.4971;45;Bottom;R51
299;;;26.5716;-53.0312;-15;Bottom;TXT41
300;;;43.8953;-57.8667;-15;Bottom;TXT41
301;100;THT;15.3886;-6.20119;-90;Bottom;R68

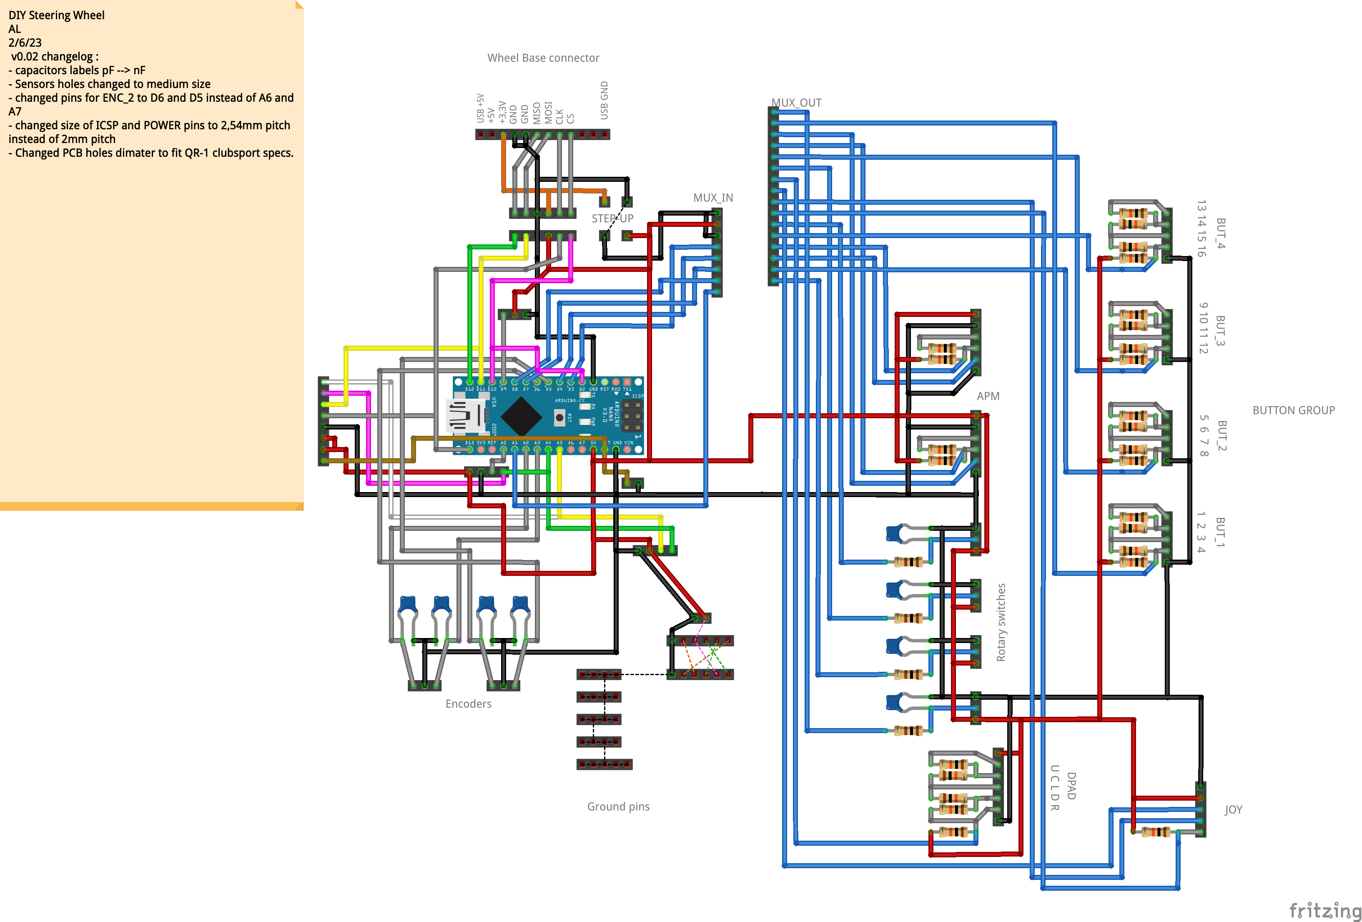
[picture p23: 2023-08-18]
F_Interface_AL_Hardware_v0.02/F_Interface_AL_Hardware_v0.02_bb.png

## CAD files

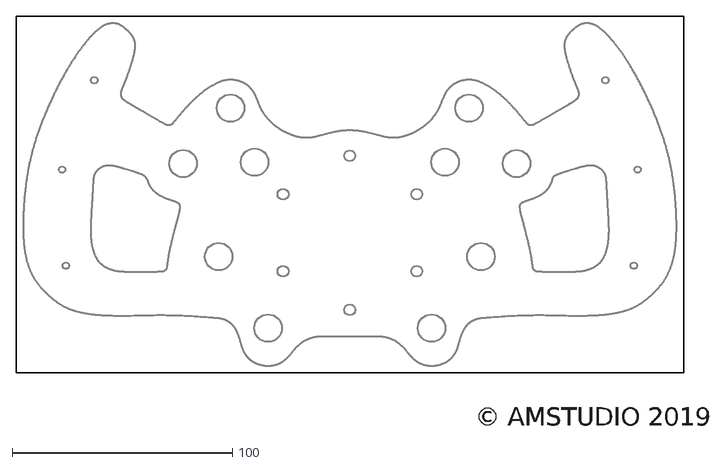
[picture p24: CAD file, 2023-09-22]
Build files/Audi_DTM_AL/Audi Wheel Template.dxf
© AMSTUDIO 2019

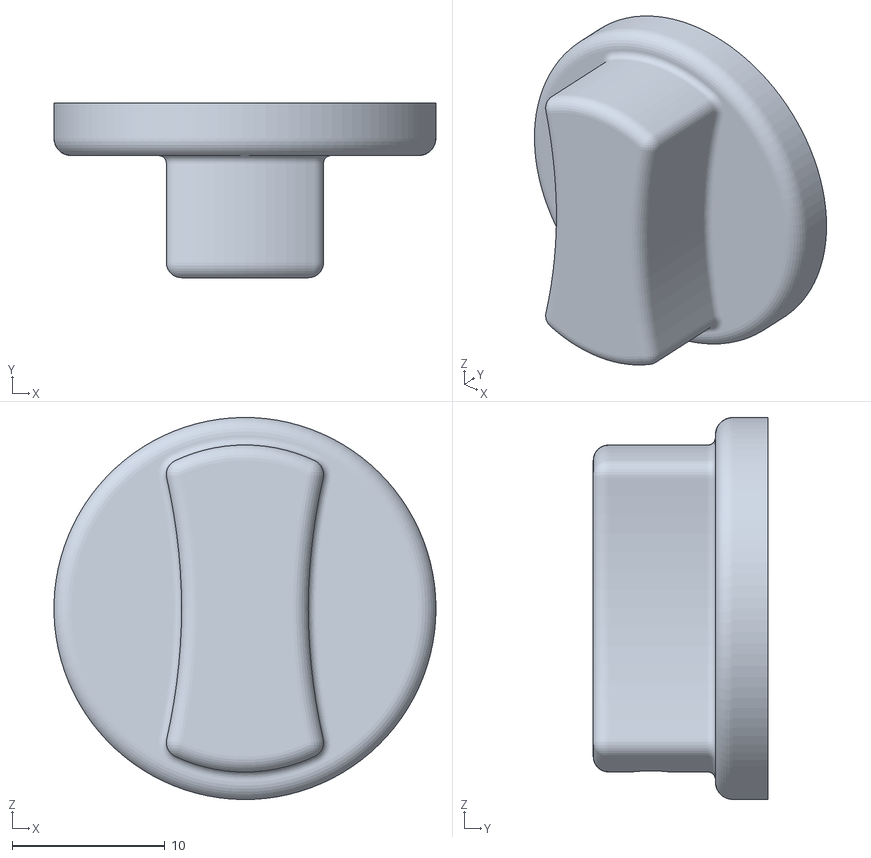
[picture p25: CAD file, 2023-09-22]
Build files/Audi_DTM_AL/Audi_DTM_AL/Rotary Knob DTM AL.stl
25.0 x 11.4 x 25.0

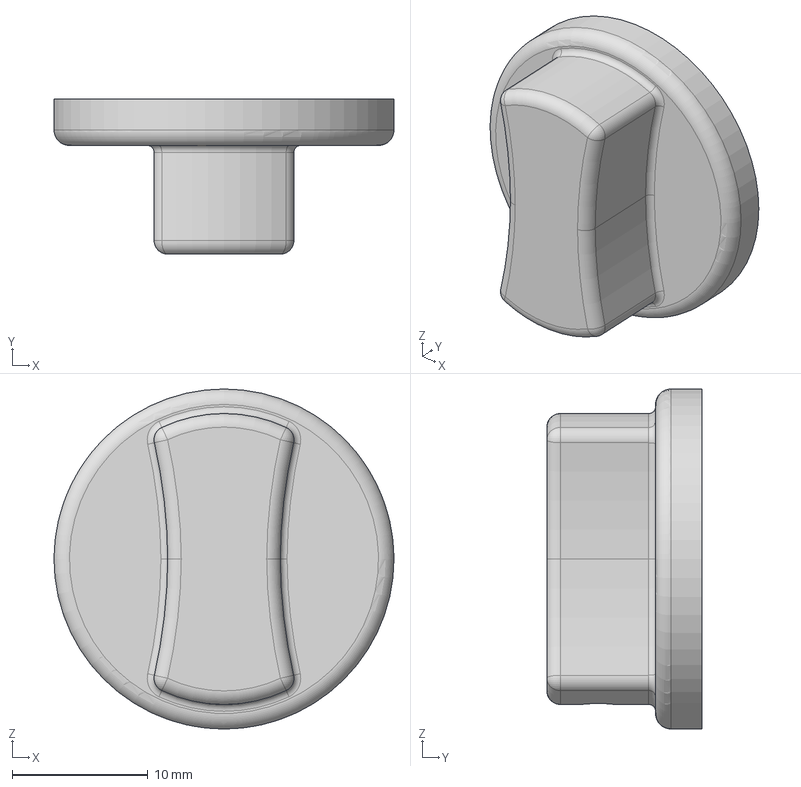
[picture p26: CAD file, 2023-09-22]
Build files/Audi_DTM_AL/Audi_DTM_AL/KNOB ROtary switch AL v2 v3.step
25.0 x 11.4 x 25.0 mm

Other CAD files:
Build files/Audi_DTM_AL/Audi_DTM_AL/KNOB ROtary switch AL v2 v3.f3d

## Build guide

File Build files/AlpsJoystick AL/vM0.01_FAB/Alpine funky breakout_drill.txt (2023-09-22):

; NON-PLATED HOLES START AT T1
; THROUGH (PLATED) HOLES START AT T100
M48
INCH
T1C0.086614
T100C0.042000
T101C0.015748
T102C0.027559
T103C0.035000
T104C0.038000
%
T1
X012798Y009376
X003622Y009376
X003622Y000820
X012787Y000827
T100
X009289Y003606
X007168Y008189
X003500Y004485
X005978Y001998
X005987Y008189
X006989Y002327
X006188Y007320
X009653Y005671
X009644Y004490
X005072Y004485
X003500Y005666
T101
X006164Y006523
X010070Y002618
X008275Y003671
X004497Y007948
X003064Y002432
T102
X010070Y000944
X008101Y000944
X010008Y009686
X010008Y007717
T103
X002258Y000602
X011000Y009500
X004892Y009562
X002196Y009562
X011000Y000634
X011000Y005500
X002196Y005562
X008892Y009562
X002258Y004602
X011000Y004634
T104
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

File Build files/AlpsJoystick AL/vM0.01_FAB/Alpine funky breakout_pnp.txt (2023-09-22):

*Pick And Place List
*Company=
*Author=
*eMail=
*
*Project=Alpine funky breakout
*Date=13:23:26
*CreatedBy=Fritzing 0.9.3b.04.19.5c895d327c44a3114e5fcc9d8260daf0cbb52806
*
*
*Coordinates in mm, always center of component
*Origin 0/0=Lower left corner of PCB
*Rotation in degree (0-360, math. pos.)
*
*No;Value;Package;X;Y;Rotation;Side;Name
1;;;30.1796;-12.912;0;Bottom;TXT1
2;;;4.07407;-21.7079;-90;Bottom;TXT1
3;10k;THT;27.9407;-19.051;90;Bottom;10K
4;;;9.20054;-23.8161;0;Bottom;Hole4
5;;;15.6575;-16.5685;0;Bottom;Via4
6;;;30.3678;-17.9622;0;Bottom;TXT1
7;;;4.02706;-11.2813;-90;Bottom;TXT1
8;;cap-pth-5mm;25.421;-22.1035;-90;Bottom;10nF
9;;;32.5076;-23.8161;0;Bottom;Hole1
10;;cap-pth-5mm;23.0785;-2.39881;-180;Bottom;10nF
11;;THT;16.6654;-12.9422;0;Bottom;JS1
12;;;4.12113;-6.34245;-90;Bottom;TXT1
13;;;11.4242;-20.1903;0;Bottom;Via1
14;;;7.78322;-6.17833;0;Bottom;Via2
15;;;4.12113;-8.83541;-90;Bottom;TXT1
16;;;10.9599;-14.1349;-90;Bottom;TXT2
17;33k;THT;5.5785;-19.2085;90;Bottom;33K
18;22k;THT;17.5063;-24.2885;-180;Bottom;22K
19;;;4.02706;-16.2045;-90;Bottom;TXT1
20;;;21.0198;-9.32477;0;Bottom;Via3
21;;THT;1.95646;-12.7214;0;Bottom;J1
22;;;30.2267;-7.69085;0;Bottom;TXT1
23;;;4.0741;-3.78677;-90;Bottom;TXT1
24;;;32.479;-2.10228;0;Bottom;Hole2
25;;;16.6999;-7.53151;0;Bottom;TXT2
26;;;4.0741;-19.0268;-90;Bottom;TXT1
27;;;4.02706;-14.0565;-90;Bottom;TXT1
28;;;9.20054;-2.08385;0;Bottom;Hole3
29;;;22.1283;-15.4049;-90;Bottom;TXT2
30;10k;THT;27.9407;-6.69141;-90;Bottom;10K
31;;;25.5785;-6.65077;0;Bottom;Via5
32;;;30.2737;-15.3108;0;Bottom;TXT1
33;;THT;32.98;-12.9093;0;Bottom;J2
34;;;30.2267;-10.3249;0;Bottom;TXT1
35;5k;THT;5.73598;-6.61013;90;Bottom;5K

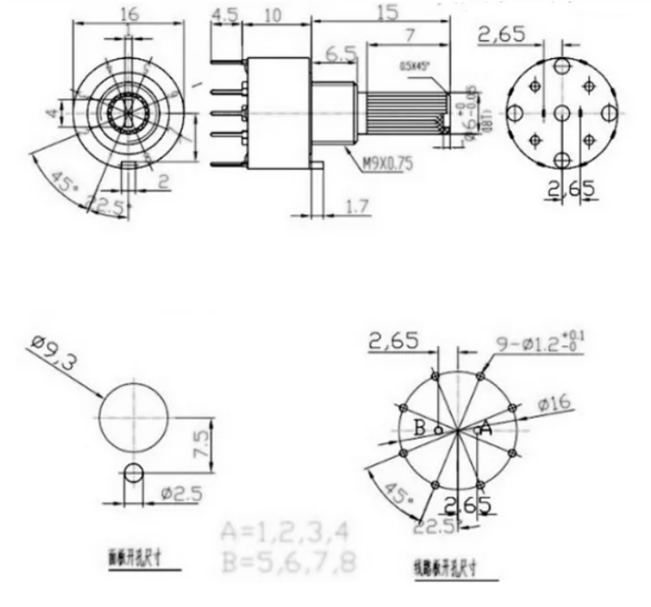
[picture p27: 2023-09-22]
Build files/RS16_PCB_AL/Capture d’écran 2023-09-18 à 15.28.50.png

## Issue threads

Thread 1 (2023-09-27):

Can you help me? There is something unclear about the schematic diagram

jz5588, 2023-09-27:
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

What is the connection between the marked position of the picture? What is the function of flying wires? I can’t understand the schematic diagram here. It would be perfect if the schematic diagram has the connected devices marked.

Alexbox364, 2023-09-28:
Hi!
Sure it’s unclear in the breadboard view.
There the ground pins row that are used for button group (bottom left of the red circle), the power supply pin (not really needed but there was som space left) and the ICSP connector of the arduino.
I’ll update the sketch to be more comprehensive.
Inbetween, you can click on a component on The breadboard view, then go to the PcB view and you’ll see where the component actually is.

jz5588, 2023-09-28:
Thank you for your help. Can this PCB be directly connected to FANATEC's wheel and connected to ARDUINO NANO's USB MICO interface for other brands of wheels?

Alexbox364, 2023-09-30:
Hi,
for the Fanatec bases yes, you’ll just need a podium hub without its original PCB to get the QR and 12 pins connector.
For other wheels you can use the micro usb of arduino nano to connect to Pc but you’ll need additional software on the Pc to turn the serial output of arduino into joystick button presses.
Like sim hub, but I never tested it. It’s highly likely you’ll have to further develop the software on the arduino nano.
It’s something I have in mind to develop connection with sim hub but it’s not done yet.

jz5588, 2023-10-03:
I need 16 WS2812RGB as speed and semaphore prompt lights. Can it be realized through the 3P socket of DO-VCC-GND?

Alexbox364, 2023-10-07:
Hi, yes, you can use as much LEDs on the NPX port as you want (keeping in mind the required mount of current).
But you’ll be limited by the data sent by fanalab

Closed 2023-11-22.

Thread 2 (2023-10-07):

I have another question for you, is it possible to directly use these two control buttons?

jz5588, 2023-10-07:
I have another question for you, is it possible to directly use these two control buttons?
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

jz5588, 2023-10-07:
Because according to your tutorial, you choose the modular button

Alexbox364, 2023-10-07:
Hi, sure, you can use them directly, they are managed independently from the 4 button groups. You’ll just need to solder the relevant resistors.
You can also use the DPAD pins as classic buttons.

jz5588, 2023-10-07:
There are already resistors on the PCB you designed. Do I need to add another resistor if I use this button directly?

Alexbox364, 2023-10-09:
Yes, just solder the resistors identified on the PCB. It’s just that if you don’t need specific group of functions on the PcB, you don’t need to solder all the components

Closed 2023-11-22.

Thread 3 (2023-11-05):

Can you help me,I don't know how to remove the arduino bootloader.

Lele1494, 2023-11-05:
Thank you for your great work！
My arduino nano already have bootloader,how to remove it?
If i burn firmware directly through the ICSP，bootloader will be overwritten？

I'm sorry, my English is very poor。I use translation software to write。
Looking forward to your reply。

Alexbox364, 2023-11-08:
Hi!
to flash the firmware without the Arduino bootloader, you can use the link in the readme : https://docs.arduino.cc/built-in-examples/arduino-isp/ArduinoISP

Alexbox364, 2023-11-08:
The process is revertable : and is described in the « program the bootloader » paragraph
https://docs.arduino.cc/built-in-examples/arduino-isp/ArduinoISP#program-the-bootloader

Lele1494, 2023-11-12:
> 该过程是可还原的：并在“程序引导加载程序”第 https://docs.arduino.cc/built-in-examples/arduino-isp/ArduinoISP#program-the-bootloader 段中进行了描述

Thank you! Already done! It worked.
 Do you know which model of wheel can use the oled display？

Alexbox364, 2023-11-12:
Hi, great 👍🏻.
In fact, whatever the wheel ID you choose (among the ones using SPI to communicate with the base), you will have access to the same amount of buttons / LEDs / 7 segments.
If you hook up an Oled display, you can just display simple data sent by the base (the one the is displayed on the 3 x 7segments digits and the number of LEDs of the rev limiter), they can be configured in Fanalab.
These 3 digits are parsed by the F_interface code and you can display it on an OLED display.

Alexbox364, 2023-11-17:
Closed

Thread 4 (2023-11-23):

Turn Racing Porsche GT3 Wheel files

Acedia5k, 2023-11-23:
In Discord you said that the Turn Racing Porsche 911 GT3R Wheel is compatible with your PCB, but it needs custom CAD files. Sadly you don't answer me on there, but I need your help there.

Alexbox364, 2023-11-30:
Just give me your email address in PM

Acedia5k, 2023-11-30:
> Just give me your email address in PM

GitHub apparently removed the PM feature, and you have not listed a contact E-Mail.

Acedia5k, 2023-11-30:
> Just give me your email address in PM

GitHub apparently removed the PM feature, and you have not listed a contact E-Mail.

Alexbox364, 2023-11-30:
Ok, then you can PM me in discord 👍🏻

Le 30 nov. 2023 à 11:59, Acedia5k ***@***.***> a écrit :

Just give me your email address in PM

GitHub apparently removed the PM feature, and you have not listed a contact E-Mail.

—
Reply to this email directly, view it on GitHub<https://github.com/Alexbox364/F_Interface_AL/issues/4#issuecomment-1833533178>, or unsubscribe<https://github.com/notifications/unsubscribe-auth/AEB36DVHMXNAZECH7L32NPLYHBRJFAVCNFSM6AAAAAA7YKIGSGVHI2DSMVQWIX3LMV43OSLTON2WKQ3PNVWWK3TUHMYTQMZTGUZTGMJXHA>.
You are receiving this because you commented.Message ID: ***@***.***>

Acedia5k, 2023-11-30:
Ok you just answered my question via E Mail, I don’t know how you did that
haha.

You can send me the files here aswell 👌🏼

Alexbox364 ***@***.***> schrieb am Do. 30. Nov. 2023 um 15:37:

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

Closed 2023-11-30.

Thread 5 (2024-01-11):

Small question about the boost circuit

thomaswang04, 2024-01-11:
I was looking at the cirucit for the stepup voltage converter and was wondering why you didnt step up the wheels 4.5v pin instead of boosting the 3.3v one? I am currently editing the pcb to work in my current wheel design and I wanted to power a raspberry pi off of it to run a sim hub display and wanted to ask if you think that the boost converter could supply the everything plus the raspberry pi and screen which i have mesured to draw about 0.5 to 0.8 amps at any given moment.

Alexbox364, 2024-01-11:
Hi!
We did so in the project because the 3,3V is powered at first by the base.
5V pin is powered later and too late to establish a SPi communication with the base.
If you wish to power your RPi and the screen, I would advise you to use the 5V pin and the USB 5V pin.
I don’t know how much currrent the base can provide safely but I wouldn’t expect too much of it.
I would suggest you to use a microcontroller to unlock the base FFB and handle the SPI communication and use the RPI to handle buttons and screen.

Alexbox364, 2024-01-11:
I don’t think the RPi alone can fire up quickly enough at base startup to unlock FFB.

thomaswang04, 2024-01-11:
I have been trying to use the 5v usb pin with the usb ground but it ends up having a weird interaction. Sometimes when the wheel is attatched the wheel goes into safe mode then reboots and does the spinning calibration thing. However sometimes I can get it working by plugging the Rpi in after the wheel connects. I think ill try boosting the 4.5v circuit for just the RPi and the 3.3 for the arduino. Thanks for your input!

Closed 2024-02-04.

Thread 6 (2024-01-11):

Button 19 is always on

dexter323i, 2024-01-11:
Hi!

First, thank you for your awesome work! I've checked all repos on github for the keyword Fanatec, and yours is the far-far most comprehensive one! It is so sad it is only on the second page of the results.

So. I try to use it on a Fanatec DD wheelbase, and it works, but button 19 is always triggered on the joystick properties panel. Is it normal? All other buttons work as intended, turns on / off as they should, but joy button 19 is always on, since the weelbase recognises the wheel, and joy axises starts to show.

Can I somehow turn joy button 19 off?
(I've tried lshachar's repo, and that also does the same)

dexter323i, 2024-01-11:
Nevermind! I have a hommade shifter plugged into the base, and totally forgot about it. That was triggering button 19. 🤦‍♂️

Closed 2024-01-11.

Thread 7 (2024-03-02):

questions about the 0.06 hardware and software

thomaswang04, 2024-03-02:
Hi alex,
Im back asking more questions again. Since I last asked a question a couple months ago I have been trying to design a board using your design to fit in my wheel, however this new one fits now.

Im making a mercedes f1 wheel but im desinging it so it has 6 rotary encoders and 2 rotary swtiches. Would it be possible to use the output pins used for the 2 screens and two of the rotary swithces for the encoders? I somewhat understand the code so i should be able to duplicate the encoder code and add left and right button bits right?

Also your button box has 10 leds, is it possible to have 21?

Sorry for asking so many questions.

Alexbox364, 2024-03-02:
Hi!
Yes, for sure you can use the LCD pins or any other pin you don’t use to hook up your extra encoders.
As encoders are already managed without interrupts in the code, you can just duplicate existing portion of code to add your extra encoders :-).
For the button box, you can use as many WS2812b LEDs as you want. I did put 8 on the PCB because it fits but I did myself preferably used a piece of 120 LEDs / m strip sticker on the PCB with 10 LEDs. 21 will also be fine :-).

thomaswang04, 2024-03-05:
Cool! I'll get that sorted when I get the chance. Does that mean you can control each WS2812b individually from the fanatec software?

Alexbox364, 2024-03-08:
Hi, no you cannot control the aRGB LEDs from Fanalab.
What you get from information on the arduino is the individual status (on / off) of each of the 9 original supported LEDs of old Fanatec wheels.
With this information, you can light up as many aRGB LEDs hooked up to the Arduino.

with Fanalab, you can decide when to light up those 9 LEDS

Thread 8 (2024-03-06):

street wheel model

Lele1494, 2024-03-06:
Thank you for your great work
Sorry,My English is not good, I am using translation software to write。
I got a question,I choose the type is NANO_WHIT_HEADER.When I defined the wheel model as P-HUB,The keypad don't work,Defined as 918, kepad work's very well.How does this need to be resolved？
 BTW,Have you made this  ATTINY_NO_HEADER  ？
It's smaller，I am very interested in this project。
Thank you again for your help

Alexbox364, 2024-03-08:
Hi, no problem 👍🏻.
Hum, that’s strange as they keypad presses are buttons presses like others. You did not change anything else in the code?
To debug it, you can observe what’s going on on the Miso SPI data by uncommenting the print_miso() function. You’ll know if the wheel actually sends d_pad data to the base.

Lele1494, 2024-03-10:
Thank you,I'll check it.
Even so, the 918 mode works perfectly。
I designed this, put the chips together directly, and it's being customized. I hope it works.
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

Lele1494, 2024-03-10:
Thank you,I'll check it.
Even so, the 918 mode works perfectly。
I designed this, put the chips together directly, and it's being customized. I hope it works.
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
The factory is making it, I will test whether it works.

Lele1494, 2024-03-18:
I'm back,it works!!
3D print shell,looks very well!
Without your code, I wouldn't have been able to do it. Thank you very much!

Alexbox364, 2024-03-19:
Hi mate, this looks very cool!
you are using an ATMEGA329P chip?
This is very tiny and can be useful for many people. Please consider sharing it on GitHub :-).
I’m working on Bluetooth based DIY and for Fanatec owners, that could be great to use you design to supply the main PcB with 5V !

Alexbox364, 2024-03-19:
And which Fanatec wheel base do you use?
because my last wheel was a clubsport DD 12Nm and my PCBs weren’t working with this base while they were working fine with my DD1.
Certainly a SPI timing issue.

Lele1494, 2024-03-20:
[unlock-shell.zip](https://github.com/Alexbox364/F_Interface_AL/files/14661698/unlock-shell.zip)
Here is the 3D print files.

Alexbox364, 2024-04-15:
Hi, thank you for sharing, I’ll add the files to the repo with your credit.

JuanTrev24, 2024-04-25:
@Lele1494 can you help me ?

Closed 2024-04-15.

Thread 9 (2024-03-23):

A question about encoders and rotary switches

Lele1494, 2024-03-23:
If I add these switches，Where will the computer recognize it？
Did it show up in fanatec's driver？How can I use them？

Alexbox364, 2024-03-23:
Hi, yes, they react as short button presses (you can choose the length, like 30ms).

Closed 2024-03-24.

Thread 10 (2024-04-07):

How to contact you

QingXY57, 2024-04-07:
Hi Alexbox364
  How do I contact you? Email？or Discord?

Alexbox364, 2024-04-15:
Hi, if it’s a question about the project you can post it here so that everyone can benefit from it.
Else discord Alexbox364, but not much active.

QingXY57, 2024-04-15:
Enable led ,OLED,TM1637,compilation will give an error for not declaring variables in advance? Or declare variables globally?
Translated by translation software

Alexbox364, 2024-04-15:
Hi, did you well install the associated libraries in your arduino IDE ahead with library manager?

Le 15 avr. 2024 à 08:28, black qing ***@***.***> a écrit :

Enable led ,OLED,TM1637,compilation will give an error for not declaring variables in advance? Or declare variables globally?
Translated by translation software

—
Reply to this email directly, view it on GitHub<https://github.com/Alexbox364/F_Interface_AL/issues/10#issuecomment-2055568601>, or unsubscribe<https://github.com/notifications/unsubscribe-auth/AEB36DXFLAZFZIMPIXFEFBLY5NXP7AVCNFSM6AAAAABF3BOTPGVHI2DSMVQWIX3LMV43OSLTON2WKQ3PNVWWK3TUHMZDANJVGU3DQNRQGE>.
You are receiving this because you commented.Message ID: ***@***.***>

QingXY57, 2024-04-15:
Associated libraries installed，After compiling, the prompt ：Compilation error: 'crc8Stat' was not declared in this scope

Alexbox364, 2024-04-17:
Hi, I'll have a look

Alexbox364, 2024-04-17:
I moved the crc8stat variable as a global variable and added pins declaration for the TM1637. Should be OK to compile. Depending on what you want to achieve with LEDs and screens, you may have to develop a bit of code.

QingXY57, 2024-04-17:
Okay, thanks.

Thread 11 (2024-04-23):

NEW UNLOCKER

Lele1494, 2024-04-23:
I have re optimized the PCB and now it is a single-layer design, thinner.
All parts can be found on the DC-DC boost board and Arduino nano.
[FFB UNLOCKER V2 PCB.zip](https://github.com/Alexbox364/F_Interface_AL/files/15072151/FFB.UNLOCKER.V2.PCB.zip)
[3dPrint.zip](https://github.com/Alexbox364/F_Interface_AL/files/15072162/3dPrint.zip)

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

Alexbox364, 2024-04-23:
Hi! Looks awesome! Good job 👍🏻.
How much costs the assembled PCB-A from Jlpcb or equivalent?

Le 23 avr. 2024 à 08:16, Lele1494 ***@***.***> a écrit :

I have re optimized the PCB and now it is a single-layer design, thinner.
All parts can be found on the DC-DC boost board and Arduino nano.
FFB UNLOCKER V2 PCB.zip<https://github.com/Alexbox364/F_Interface_AL/files/15072151/FFB.UNLOCKER.V2.PCB.zip>
3dPrint.zip<https://github.com/Alexbox364/F_Interface_AL/files/15072162/3dPrint.zip>

3D_DC._2024-04-23.png (view on web)<https://github.com/Alexbox364/F_Interface_AL/assets/149867907/41183443-07e4-4697-8902-6d6f985342aa>
3D_DC.2_2024-04-23.png (view on web)<https://github.com/Alexbox364/F_Interface_AL/assets/149867907/30f837bb-7b28-454a-8d69-a51e567f2110>
_20240423140729.jpg (view on web)<https://github.com/Alexbox364/F_Interface_AL/assets/149867907/aba4bac1-bd2d-4813-a6a2-2b2e4f736bc5>
_20240423140733.jpg (view on web)<https://github.com/Alexbox364/F_Interface_AL/assets/149867907/68d3f533-086d-43cc-901e-180859c2a2b6>
_20240423140737.jpg (view on web)<https://github.com/Alexbox364/F_Interface_AL/assets/149867907/06c1e2a4-7ec8-4271-bf3e-78b27eaf4981>
_20240423140740.jpg (view on web)<https://github.com/Alexbox364/F_Interface_AL/assets/149867907/d14cbfa2-7d9a-4c21-99bd-007b3f76f2b9>

—
Reply to this email directly, view it on GitHub<https://github.com/Alexbox364/F_Interface_AL/issues/11>, or unsubscribe<https://github.com/notifications/unsubscribe-auth/AEB36DXXVKE6WCBKKB3AUQLY6X4E3AVCNFSM6AAAAABGUEUP3KVHI2DSMVQWIX3LMV43ASLTON2WKOZSGI2TQMBTG44TGNI>.
You are receiving this because you are subscribed to this thread.Message ID: ***@***.***>

Lele1494, 2024-04-23:
I live in China, there is a PCB manufacturer called Jialichuang. PCB customization is free of charge, and if you spend money on customization, it does not exceed 20RMB. Including other parts, the cost does not exceed 50RMB

Lele1494, 2024-04-23:
I live in China, there is a PCB manufacturer called JLCPCB. PCB customization is free of charge,
 and if you spend money on customization, it does not exceed 20RMB. Including other parts, the cost does not exceed 50RMB

johnysed, 2024-04-29:
Hey, do you have the schematics, or at least components list?
What ATMEGA is it exactly? Thanks

Lele1494, 2024-04-30:
> 嘿，你有原理图，或者至少是元件列表吗？它到底是什么ATMEGA？谢谢

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
they all can find on the arduino nano and dc-dc booster. Note that the chip must be mega328p,not the 328pb

Krakane, 2024-05-03:
hello nice job I would like to do it I have a few questions and a problem. to start the pcb file don't go to jlcpcb when I add the compressed file it remains blocked at 96% I don't know why with different browser it's the same. If I understood correctly, it is necessary to unsolder all the components of the two cards? and where to find the connection pins you use. ? thank you in advance for your feedback

Lele1494, 2024-05-04:
The PCB is labeled with the original model number, so you only need to remove the parts you need. You can program the chip and then remove it, or you can install it and program it again. The ICSP programming interface is reserved.
The connection pins like in the picture
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

Krakane, 2024-05-04:
thank you for the answer on the other hand I apologize but to unlock the FFb you have to program the chip? (that was my question, I don't know if I was clear at the beginning) and if that's the case where can I find the code?

johnysed, 2024-05-06:
> thank you for the answer on the other hand I apologize but to unlock the FFb you have to program the chip? (that was my question, I don't know if I was clear at the beginning) and if that's the case where can I find the code?

The code is in the parent folder in this github.

Krakane, 2024-05-06:
> > thank you for the answer on the other hand I apologize but to unlock the FFb you have to program the chip? (that was my question, I don't know if I was clear at the beginning) and if that's the case where can I find the code?
>
> The code is in the parent folder in this github.

ok i understand i try that when i recevied my composant thank you

xFoxHound, 2024-05-10:
bonjour , je ne parviens pas a trouver le bon fichier zip avec le pcb en monocouche , pourriez vous me donner les informations  nécessaire ? Merci beaucoup

Krakane, 2024-05-20:
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
hi I soldered my pcb beforehand I had programmed my chip on my arduino card and I unsoldered it to put it on the pcb as soon as I plug in my dd2 base the screen goes out and "no" steering wheel detected

johnysed, 2024-05-25:
Yeah, also can't get it to work. The comm LED is lit up, program is running but still no detection of the wheel.

Lele1494, 2024-05-28:
> ![IMG_1583](https://private-user-images.githubusercontent.com/34950473/332118380-a5bb8fb8-43d2-414a-bfa7-7038861ed397.JPEG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)嗨，我事先焊接了我的 pcb，我已经在我的 arduino 卡上编程了我的芯片，然后我拆下它以将其放在 pcb 上，一旦我插入我的 dd2 底座，屏幕就会熄灭并检测到“无”方向盘

must flash the bootloader first,then flash th code.

Lele1494, 2024-05-28:
> Yeah, also can't get it to work. The comm LED is lit up, program is running but still no detection of the wheel.

must flash the bootloader first,then flash the code.

Alexbox364, 2024-05-28:
Hi, to have the at mega to communicate with the base quickly enough, you have to flash the code with ICSP port.
When I had the base going out it mainly was because the at mega wasn’t firing the spi communication quick enough at startup

johnysed, 2024-05-29:
> > Yeah, also can't get it to work. The comm LED is lit up, program is running but still no detection of the wheel.
>
> must flash the bootloader first,then flash the code.

Why would I have to flash the bootloader first? Im trying to run the code without bootloader, so it's as fast after start as possible.
I used ICSP programmer.

Alexbox364, 2024-05-29:
Do you still have a serial output?
And what is you wheelbase?

Lele1494, 2024-05-30:
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

At first, I did the same thing, but it didn't work. Later, I found out that the blank chip had to be written into the bootloader and then uploaded through the programmer to work.I'm not sure about the specific reason, maybe it's because we need raw partitions or something。

Krakane, 2024-05-30:
Thank you for your information, do you have a tutorial to follow to do this? I know a little about arduino but I admit I don't understand everything ;p

johnysed, 2024-05-30:
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

Burned the bootloader and loaded in the program. Now it's not replying fast enough. Are you running it with the bootloader in?

johnysed, 2024-06-02:
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

I loaded the bootloader in, but now I have stability issues. It successfully connects like 1 out of 10 times.
How is your connection stability?

Lele1494, 2024-06-07:
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
You try to grind this needle off by 1mm according to the picture
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

RoGPoWeR, 2024-07-06:
Hi Lele, idk if you are italian or not but i have a question for you, how i can program the chip if i buy it as spare? If i build all the pcb is there a method to program through the pins? Thanks

Lele1494, 2024-07-10:
> Hi Lele, idk if you are italian or not but i have a question for you, how i can program the chip if i buy it as spare? If i build all the pcb is there a method to program through the pins? Thanks

The 6pin port on the pcb is ISCP program port.

RoGPoWeR, 2024-07-10:
> Thanks

And wich firmware do i have to use? Is the stm32 usb programmer good for programming it?

RoGPoWeR, 2024-07-13:
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

And wich firmware do i have to use? Is the stm32 usb programmer good for programming it?

TFYR-RTY, 2024-11-14:
>我住在中国，有一家名为JLCPCB的PCB制造商。PCB定制是免费的，如果你在定制上花钱，它不会超过20元人民币。包括其他部分在内，成本不超过50元人民币>我住在中国，有一家名为JLCPCB的PCB制造商。PCB定制是免费的，如果你在定制上花钱，它不会超过20元人民币。包括其他部分在内，成本不超过50元人民币老板有qq联系方式吗

jz5588, 2024-12-11:
If I want to save the USB cable of my wheel, I can connect the USB output of my wheel to pin 9 (USB charge 5V) pin 11 (USB charge GND) pin 10 (DataPort1) pin 12 (DataPort2) through the FANANTEC base to the PC, because the pins look like USB 5V GND DP DN

jz5588, 2024-12-11:
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

creagel, 2025-05-15:
Is it possible to get BOM and CPL file?

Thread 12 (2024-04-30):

BOM

maximilianschulte, 2024-04-30:
Could you make the BOM's (especially for ATMEGA328P_NO_HEADER) more specific. There are some parts that are not described, espacially the crystal oscillator and the capacitors. I'd also be interested in the 12 pin connector used as the fanatec connector. I'm quiet new to all that stuff, so sorry in advance if i missed anything.

Alexbox364, 2024-04-30:
Hi, to help you start, AliExpress kits for ATMEGA328p are a good base with included oscillator

https://a.aliexpress.com/_EJlHjkn

About the Fanatec connector you mean the QR pins of the 12x 2mm pitch pins on the PCB?

Le 30 avr. 2024 à 11:45, maximilianschulte ***@***.***> a écrit :

Could you make the BOM's (especially for ATMEGA328P_NO_HEADER) more specific. There are some parts that are not described, espacially the crystal oscillator and the capacitors. I'd also be interested in the 12 pin connector used as the fanatec connector. I'm quiet new to all that stuff, so sorry in advance if i missed anything.

—
Reply to this email directly, view it on GitHub<https://github.com/Alexbox364/F_Interface_AL/issues/12>, or unsubscribe<https://github.com/notifications/unsubscribe-auth/AEB36DWFOAB2AKPULXQEEFTY75R2LAVCNFSM6AAAAABG75FNI2VHI2DSMVQWIX3LMV43ASLTON2WKOZSGI3TCMBQGQ4TEMI>.
You are receiving this because you are subscribed to this thread.Message ID: ***@***.***>

maximilianschulte, 2024-04-30:
No i mean the white connector comming from the ribbon cable. Thanks for the Atmega Kit, already ordered it.

Krakane, 2024-05-20:
Hi , i don't find the 4n7001 diod for full pro micro have you a link ?

Alexbox364, 2024-05-29:
Hi, sorry for late reply, there’s a mistake in item code, it’s 1N4001 diod

Alexbox364, 2024-05-29:
Its role is to have a voltage drop of the 5V to 3,7v on miso line

Closed 2024-06-06.

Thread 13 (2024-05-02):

Help

JuanTrev24, 2024-05-02:
Hello
I made ATMEGA328P_WITH_HEADER hoping to make it work but the programming is quite difficult for me it has caused me a big headache and I would like to use my wheel but I find it impossible is there any way even just to unlock the ffb ? Is there any way to just insert the code or something like that ?
Thanks

JuanTrev24, 2024-05-02:
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

Alexbox364, 2024-05-02:
Hi, for this version of the FFB unlocked, you will need to flash the code in the ATMEGA via ICSP method.

You need another arduino uno / nano / … to do this. I placed a link in the description to help you do it.

Le 2 mai 2024 à 09:40, JuanTrev24 ***@***.***> a écrit :

Hello
I made ATMEGA328P_WITH_HEADER hoping to make it work but the programming is quite difficult for me it has caused me a big headache and I would like to use my wheel but I find it impossible is there any way even just to unlock the ffb ? Is there any way to just insert the code or something like that ?
Thanks

—
Reply to this email directly, view it on GitHub<https://github.com/Alexbox364/F_Interface_AL/issues/13>, or unsubscribe<https://github.com/notifications/unsubscribe-auth/AEB36DTKOC3ITSX2JZQOWPDZAHUVDAVCNFSM6AAAAABHDGDHDKVHI2DSMVQWIX3LMV43ASLTON2WKOZSGI3TIOBTGMYTGNQ>.
You are receiving this because you are subscribed to this thread.Message ID: ***@***.***>

JuanTrev24, 2024-05-03:
Thank you for taking the time to respond to me. This is the problem I'm facing for now.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

JuanTrev24, 2024-05-07:
I don't know what happened, I just know that it works.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

Alexbox364, 2024-05-07:
Hi! Good news. Problem was on uploading the code to the at mega?

Le 7 mai 2024 à 17:05, JuanTrev24 ***@***.***> a écrit :

I don't know what happened, I just know that it works.4E4BFF0F-C894-4A0F-8554-877F02FB1AF5.jpeg (view on web)<https://github.com/Alexbox364/F_Interface_AL/assets/167269259/e37afeab-c512-4bcc-9ca9-ba150ee4e803>

—
Reply to this email directly, view it on GitHub<https://github.com/Alexbox364/F_Interface_AL/issues/13#issuecomment-2098639727>, or unsubscribe<https://github.com/notifications/unsubscribe-auth/AEB36DRCA4SQJWZVQANV4MTZBDUUBAVCNFSM6AAAAABHDGDHDKVHI2DSMVQWIX3LMV43OSLTON2WKQ3PNVWWK3TUHMZDAOJYGYZTSNZSG4>.
You are receiving this because you commented.Message ID: ***@***.***>

Krakane, 2024-05-20:
Hi , i don't find the 4n7001 diod for full pro micro have you a link ?

Closed 2024-05-29.

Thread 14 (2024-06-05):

On off problem with the "F_Interface_AL_v0.02" board

Garci989, 2024-06-05:
Hi Alexbox364,
I'm having problems with the board because when I plug it in my CSW2.5 it connects and disconnects for 3-5 seconds and it disconncts. I've checked and uploaded the program 5 times but the result is the same. Maybe I'm jumping one step. I wish you can help me and thanks for your work

https://github.com/Alexbox364/F_Interface_AL/assets/171802651/dc92be6b-d6b1-4b3c-a0fa-17e4ce76b433

Alexbox364, 2024-06-06:
Hello! Which version of PCB are you using?
I never had this issue. But to help understand and debug, it would be nice to have the serial port output cjecked

Garci989, 2024-06-06:
It's the F_Interface AL vM0.02
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

Garci989, 2024-06-07:
I've checked different components and when I change the step up regulator with a 5V DC input it works. I checked the step up regulator and it gives the 5V that the arduino needs. Any sugestion about it?

Garci989, 2024-07-09:
Hi again, I've tried changing to v0_06 but I had the same problem but when I'm trying to use a nano esp32 It doesn't even compile

Garci989, 2024-07-15:
I've tried the v0-02 and v0-06 versions even the v0-06 with the nano esp32 but 0 results. The only progress that I had is in the v0-02 jumping the step up voltage regulator but appeared the wrc wheel in screen and I couldn't press any button. No gonna lie, if I it wasn't because of the money I would be already gived up. If someone can help me I will really appreciate it.

Garci989, 2024-07-15:
Sorry I closed it by mistake

Garci989, 2024-07-15:
I've tried the v0-02 and v0-06 versions even the v0-06 with the nano esp32 but 0 results. The only progress that I had is in the v0-02 jumping the step up voltage regulator but appeared the wrc wheel in screen and I couldn't press any button. No gonna lie, if I it wasn't because of the money I would be already gived up. If someone can help me I will really appreciate it.

Garci989, 2024-07-16:
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
Sometimes it looks like it wants to do something and the start button leds start spinning but it doesn't do nothing more. Any help?

J3161, 2025-01-16:
Bad soldering

Closed 2024-07-15.

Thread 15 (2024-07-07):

Base disconnecting from PC

AVM88, 2024-07-07:
Used ful NANO,programed it with full nano in wheel_cfg.
but when i insert it in bese its just disconnect from PC.
double checked connector wiring...

RoGPoWeR, 2024-07-07:
Have you used dc-dc boost?

AVM88, 2024-07-07:
If u mean 3v to 5v - yes.

AVM88, 2024-07-07:
Voltage is ok,in 2.98v out 5,1

RoGPoWeR, 2024-07-07:
Post a picture here and the pin side

AVM88, 2024-07-07:
> Post a picture here and the pin side

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

RoGPoWeR, 2024-07-07:
Sorry, wheel side pin…are you using the original fanatec connector?

AVM88, 2024-07-07:
> Sorry, wheel side pin…are you using the original fanatec connector?

No,printed one. Checked pin positions few times.

RoGPoWeR, 2024-07-07:
Give me a private contact if you want i can explain better

RoGPoWeR, 2024-07-07:
Anyway you have to drill one pin like this 1mm
picture 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

If the problem persist double check if there is a short circuit

AVM88, 2024-07-07:
Already checked for shorts,both sides of connector not shorted,when pluged without arduino

AVM88, 2024-07-07:
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

AVM88, 2024-07-07:
Even made MICRO_NO_HEADER,but same problem.

RoGPoWeR, 2024-07-07:
You dont have to remove but if you see my photo one pin is short than others 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

From right side the second one

RoGPoWeR, 2024-07-07:
Sorry, how you are programming the chip?

AVM88, 2024-07-07:
> Sorry, how you are programming the chip?

programed with arduino IDE

RoGPoWeR, 2024-07-07:
I'm seeing that red wire connected to ground, it's the ground wire of the connector?

AVM88, 2024-07-07:
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
checked it  few times,visual and with multimeter

RoGPoWeR, 2024-07-07:
Have you selected the right board in arduino ide in wheel.h section?

AVM88, 2024-07-07:
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

AVM88, 2024-07-07:
Polarity of diode checked.

RoGPoWeR, 2024-07-07:
If disconnect when you plug the arduino i think there is a problem with a circuit, the code is correct if you have selected full nano, is your board full nano?

AVM88, 2024-07-07:
> If disconnect when you plug the arduino i think there is a problem with a circuit, the code is correct if you have selected full nano, is your board full nano?

Yes i was trying to build MICRO_WITH_HEADER,but ahd same problem.

RoGPoWeR, 2024-07-07:
Micro is different than nano, you can only flash nano board

AVM88, 2024-07-07:
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

Even tryed this one,and it was same... then i checked connector again,everithing seems ok.

AVM88, 2024-07-07:
> Micro is different than nano, you can only flash nano board

Micro with micro code and micro wiring.

RoGPoWeR, 2024-07-07:
Yes but the chip on the board is different

AVM88, 2024-07-07:
> Yes but the chip on the board is different

I know,but there is option supporting it....

Alexbox364, 2024-07-07:
Hi! I had this issue when the arduino did not boot quick enough at startup.
Is it working if you supply 5V from usb cable?

Alexbox364, 2024-07-07:
And which wheelbase do you use?

AVM88, 2024-07-07:
> And which wheelbase do you use?

CSL DD

RoGPoWeR, 2024-07-07:
Hi Alex, do you know what sketch i have to upload on the board of lele? And can i upload without usb?

AVM88, 2024-07-07:
> Hi! I had this issue when the arduino did not boot quick enough at startup. Is it working if you supply 5V from usb cable?

no working with USB,do i need to desolder power from step up voltage,and try then?

RoGPoWeR, 2024-07-07:
Have you desoldered the two resistors from dc-dc boost? It came in 12v

AVM88, 2024-07-07:
> Have you desoldered the two resistors from dc-dc boost? It came in 12v

Yes

AVM88, 2024-07-07:
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

AVM88, 2024-07-07:
cathode to wheel side

RoGPoWeR, 2024-07-07:
Is the right diode?

AVM88, 2024-07-07:
1N4001

RoGPoWeR, 2024-07-07:
Can i see all the connection/soldering between all the boards?

AVM88, 2024-07-11:
yellow wire mesure 3v,but wiring diagram

> ![Untitled](https://private-user-images.githubusercontent.com/18098097/346362710-b0ee9905-2933-4c27-a663-0e035ef16b5c.png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) checked it few times,visual and with multimeter

Yellow wire show 3v on multimeter,but on diagram it is  gnd together with orange wire (pin 3 and 5).  what i am missing?

AVM88, 2024-07-11:
something wrong with me or this wiring picture. :)

AVM88, 2024-07-11:
when i unsolder yellow wire,no more base disconnecting from PC (short was between orange and yellow)

RoGPoWeR, 2024-07-17:
I have your same problem but with MICRO_WITH_HEADER, when i plug into csl dd the base disconnecting from pc, have you solved the problem? I've tryed to burn bootloader, upload code, upload code with isp but no result

RoGPoWeR, 2024-07-18:
> when i unsolder yellow wire,no more base disconnecting from PC (short was between orange and yellow)

Just unsoldered that wire and no disconnection but no wheel recognised

RoGPoWeR, 2024-07-18:
I have an update, builded a nano without header and if i plug usb in the nano it's recognised by the base as a podium but without usb connected when i power up the base it disconnect

RoGPoWeR, 2024-07-20:
No one can help?

RoGPoWeR, 2024-08-09:
> when i unsolder yellow wire,no more base disconnecting from PC (short was between orange and yellow)

It's not a short issue but after milion try i've figured out the problem is the nano, i've buyed many type of nano but only one type is good for me and work perfectly on all the pcb's!

AVM88, 2024-08-09:
Which one is it,what is difference?

RoGPoWeR, 2024-08-09:
Idk what is the difference but the chip is atmega328p and not PB and you have to flash the cod through icsp port and not by usb

RoGPoWeR, 2024-08-09:
> Which one is it,what is difference?

Add me on discord my nick is rogpower we can help each other, i have found the brand of the board

For ALL, all type of code is detected as PODIUM HUB (FULL_NANO also) and the podium hub haven't the 7seg display, leds and other stuffs, tryed this stuff on full nano without chance to get it work

rcalleso, 2024-12-30:
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

Hi RoGPoWeR, still dealing with this project? I've added you on discord

J3161, 2025-01-16:
Hi everyone can someone explain to me what code I need to run to make the atmega328pu with header work  plz. Thanks

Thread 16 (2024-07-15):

Some info with Lele board

RoGPoWeR, 2024-07-15:
Hi all, what firmware in the github i have to upload in arduino nano for this project? I have nano and booster and want to program it befor desolder all and solder on the board, can anyone explain all the process and if i have to flash bootloader first? Thanks

Closed 2024-08-09.

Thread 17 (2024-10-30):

Full nano buttons don't work

RoGPoWeR, 2024-10-30:
Hi, i have tryed the full nano sketch with full nano pcb but the matrix button don't work, i've activated it in the sketch but no button, encoder or other work...only emulator tryed porsche 918 and not as podium hub, with podium hub code i have same problem

Alexbox364, 2025-01-08:
Hi, before to test it on the wheel, does it work in the serial monitor of the arduino IDE?

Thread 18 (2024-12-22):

Cubsport DD+ compatibility

dexter323i, 2024-12-22:
Hi!

Thank you for your awesome work! I’ve made a few wheels using this project with slight modifications for friends, and everyone is thrilled with the results! :) I decided to emulate the Porsche 918 RSR wheel because it has the most buttons.

One of my friends sold his wheel to someone with a new Fanatec DD+ wheelbase, but it didn’t work! When the wheelbase starts, it begins the initialization process but stops after 1-2 seconds. That’s it. The Fanatec app on Windows shows no wheel is attached. However, the wheel still works perfectly on other wheelbases.

Has anyone else experienced issues with the DD+? I don’t have access to this wheelbase, so I’m not sure what to check.

RoGPoWeR, 2024-12-22:
Hi, have you uploaded sketch as 918 rsr?

dexter323i, 2024-12-22:
I am not sure I understand your question. In my outgoing Fanatec messages the header is 0xA5, and the id is 0x03

RoGPoWeR, 2024-12-22:
Try 0x0C (is the podium hub) and check in fanatec interface tab in the arduino ide if the hex correspond to podium hub, i can't remember now and let me know if it work

dexter323i, 2024-12-24:
As I said, I don't have a DD+ base. One of my friends ordered it, but it will arrive only in January. :(
That is why I was asking for experiences from others here, maybe...

Bob2345de, 2024-12-31:
Had a similar issue using code designed for the older belt drive fanatec bases on a dd1. Turned out that the newer bases expected spi communication to start-up faster than the arduino could boot. Options were to use faster arduino/Mcu or remove arduino bootloader which speeds up boot process. DD+ could be expecting even faster spi startup. See here: https://github.com/lshachar/Arduino_Fanatec_Wheel/issues/14#issuecomment-1998003246

Alexbox364, 2025-01-08:
Hi everyone!
I made the move to jump from a DD1 to a DD+ Fanatec base and also had my wheels unable to work. It tried to find the cause of this misfunction by tweaking / sneaking the SPI protocol but could find the solution.
for this reason, I switched to Simagic and had all my wheels converted to Bluetooth and works like a charm.

dexter323i, 2025-03-10:
Some update: I converted the code to Attiny414, and left only the parts I needed for my project. Still didn't work. Then I hooked up a logic analyzer, and found out the problem!
The base only sends two 33 byte messages to the wheel. If the second reply is still not correct, then it is "game over". This is the smaller issue, the larger one is the SPI interrupt routine takes too long! I put a debug I/O pin flip at the end of the routine, and it only flipped the pin, when the base was already sending the second byte! So the solution was to make the routine as quick as possible!
I cannot check it with a Nano. If you can, then try this:

```
/////////////////////////////////////////////
// SPI interrupt routine
ISR(SPI_STC_vect)
{
  #ifdef AVR_BOARD
    data_in.raw[isrIndex] = SPDR;
    SPDR = data_out.raw[++isrIndex];
  #endif
}
```

graydonhall, 2025-06-25:
Alexbox, if you are still monitoring this repo could you please answer this question. Does the latest code in the repo work with the Nano ESP32 (at least for your old wheelbase)? Looking at the pins.h file under the ESP32 section most of the pin definitions are just set to "1". There is also a lot of code that only runs if AVR_BOARD has been defined and the ESP32 is not AVR. I'm not a programmer and I'm trying to absorb and make sense of as much of this as I can but I will only have a chance of success if I know this code has worked at some point in time.

graydonhall, 2025-09-07:
If your nano still has the bootloader installed, there is a delay between the board receiving power and the sketch executing. This delay is too long for the wheelbase. You need to upload the sketch with a programmer instead of just using Arduino IDE to upload the sketch. Have a look here:

https://docs.arduino.cc/built-in-examples/arduino-isp/ArduinoISP/

What wheelbase are you using?

J3161, 2025-09-07:
Hi I'm using a csl elite as a donor base to get everything working but my main wheel is the DD pro. Here are the shunts I soldered in marking red

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

J3161, 2025-09-07:
Graydonhall are you in discord I'm trying to send a video here but it won't upload. Thanks

graydonhall, 2025-09-07:
Yup, Graydonculous

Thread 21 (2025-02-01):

PROMICRO connection question

OndaSag, 2025-02-01:
Hi i want to use the PROMICRO variant, to connect it to the base should i use the attiny pcb also (so printing 2 pcbs)?
Also would the FFB be unlocked or should i in some way print and assemble that also.

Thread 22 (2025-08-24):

Need some advice plz

J3161, 2025-08-24:
Hi I am trying to build the full nano emulator with the f interface PCB version 6.0 few questions are do I have to shunt with resistor on PCB? and do you have to connect all 12 pins to the PCB and has anyone managed to flash the code to esp32.

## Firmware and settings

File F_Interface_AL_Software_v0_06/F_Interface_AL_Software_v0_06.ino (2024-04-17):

// This code is inherited from the Simhub original Arduino code but modified to 
// take digital input from MCP23017 GPIO expander

// Reads a button matrix attached to a MCP23XXX pin and rotary encoders. 
/* Changelog :

v0.05 :
- added support of v0.05 hardware version

v0.06 :
- added compatibility for all variants

*/
// ok to include only the one needed
// both included here to make things simple for example
#include <Adafruit_MCP23X17.h>
#include <math.h>
#include "pins_arduino.h" 
#include "F_interface_AL.h" 
#include "pins.h" 


#define AVR_BOARD

#define PIN_TYPE_A

#ifdef AVR_BOARD
  #include <avr/pgmspace.h>
#else
  #include <pgmspace.h>
#endif

#include <Adafruit_NeoPixel.h>

#if defined(BUTTON_BOX_PRO_MICRO) || defined(FULL_MICRO) || defined(MICRO_WITH_HEADER) 
  #include <Joystick.h>
#endif  

//////////////////////////////////////////////////////////////////////////////
// CONFIG - Choose your correct configuration file or create your own       //
#include "config_wheel.h" 
//#include "config_wheel_992.h" 
//////////////////////////////////////////////////////////////////////////////

#define dataLength 33
#define PRINTBIN(Num) for (uint32_t t = (1UL << (sizeof(Num) * 8) - 1); t; t >>= 1) //Serial.write(Num& t ? '1' : '0'); // Prints a binary number with leading zeros (Automatic Handling)

void yield_F();                         // function that run time essential sub-fonctions to avoid code blocking by long-time executing other ones. For example intterupt routines have to be run frequently enough
void ISR_MCP();                       // Handles interrupt of the MCP23017 for rotary encoders
void handle_ISR();                    // Handles the interrupt ISR results asynchroneously in the main loop
void set_MCP_listenning_BMX();        // Configure MCP inputs and outputs to detect a button press and trigger interrupt
void set_MCP_scan_cols_BMX(int int_pin);  // Configure MCP inputs and outputs to check a particular row
 void readButtonMatrix();              // reads the button matrix status to check if button is pressed
void inputs_management();             // handles button presses, rotary switches,....
void buttonMatrixStatusChanged(int buttonId, byte Status); // Call back function when a button status has changed in the button matrix
void printBin2(byte aByte);   // Prints binary with leading zeroes
void serialOutput();                      // Prints I/O state to Serial Output
void printmosibuf();                      // Prints MOSI buffer to Serial Output
void printmisobuf();                      // Prints MISO buffer to Serial Output
void printHex(int num, int precision);
void printButtonByteToSerial();           // Prints the selected button byte to Serial, if it was changed. The button byte can be selected by sending either A,B or C through the serial monitor. The bits in the selected button byte can either be changed by the serial monitor (sending 1 to 7 raises / lowers a specific bit,) or by pressing one of the physical buttons, if you have any attached.
void cableselect();                       // When CS line goes high - the rim should get ready to transmit the next returnData buffer, right from the begining. (so that the first byte (0xA5) will be sent out on the first Clock cycle (and after CS line went Low)
void calcOutgoingCrc();
bool checkIncomingCrc();
//ISR(SPI_STC_vect);           // SPI interrupt routine
uint8_t crc8(const uint8_t* buf, uint8_t length);     // return CRC8 from buf

void update_rev_LEDS();               // Get data received from the base about the 9 rev LEDS, parse them and displays them.
void update_7_segments();             // Get data received from the base about the 3x 7 segments displays, parse them and displays them.
void update_OLED();                   // Get data received from the base about the display information, parse, process them and displays them on the OLED
void play_init_rev_LEDs();            // Plays initialization animation

void test_output();   // test inputs of the wheel
void test_leds();     // test LED output of the wheel
void test_7segments();    // test 7 segments display

void buttonBitChange(uint8_t buttonBit, bool bitOn);    // Changes the value of a given buttonBit
void buttonBit_buffer_handling();     // handling of button presses buffer, mostly required by impulsion based interfaces like encoders & rotary switches
unsigned long lastButtonPress;
unsigned long lastPoll;

bool crc8Stat;

Adafruit_MCP23X17 mcp;

uint8_t encoder_plus = 0b00000001;
uint8_t encoder_less = 0b11111111;

fanatec_data_in_t data_in;
fanatec_data_out_t data_out;

/////////////////////////////////////////////////////
// Current values variables
    
    bool flag_ISR = 0;          // Boolean to trigger the action of MCP23017 interrupt

    // Rotary switches management
    int rs_val[4];                                  // Rotary switch current position, ranging from 0 to 7
    int old_rs_val[4] = {1023, 1023, 1023, 1023};   // Rotary switch previous position, ranging from 0 to 7
    int old_FUNKY_val;  // Rotary switch previous position, ranging from 0 to 7
    int old_DPAD_val;   // Rotary switch previous position, ranging from 0 to 7
    int rs_pos [4] = {0, 0, 0, 0};                  // integrated position of rotary switches
    int current_analog_RS_val[4];                   // Current analog Raw position
    int val_eval, val_eval2, val_eval3, val_eval4;  // Processed value to determine if rotary switch analog value is usable
    unsigned int last_RS_measure;
    int oldValRS1 = 0;
    int oldValRS2 = 0;
    int oldValRS3 = 0;
    int oldValRS4 = 0;
    
    unsigned long tempo = 0;          // timer for 1s in main loop
    // Button matrix variables
    byte BMATRIX_COLSDEF[8] = { BMATRIX_COL1, BMATRIX_COL2, BMATRIX_COL3};
    byte BMATRIX_ROWSDEF[8] = { BMATRIX_ROW1, BMATRIX_ROW2, BMATRIX_ROW3, BMATRIX_ROW4, BMATRIX_ROW5, BMATRIX_ROW6, BMATRIX_ROW7};
    uint8_t buttonState;
    unsigned long buttonLastStateChanged;
    unsigned long lastButtonPress_BMX;      // to record the instant when the button was pressed
    int lastButtonPress_BMX_ROW = 0;        // to record the row of the button pressed
    int lastButtonPress_BMX_COL = 0;        // to record the column of the button pressed
    bool FLAG_buttonPressed = 0;            // to flag that a button has been pressed in the button matrix and wait for it to be released
    bool FLAG_buttonPressedConfirmed = 0;   // to flag that a button has been CONFIRMED pressed in the button matrix and wait for it to be released
    int pressedButton;   // a text string  like 11, 12, 13.....17, 21, 22,...., 27, 31, 32 - coded like  column*10 + row
    int pressedButtonID;  //ranging from 0 to 20
    int lastPressedButton;
    int lastPressedButtonID;
    int pressedButton_ISR;  // for a buick detection by ISR handling  routine - a text string  like 11, 12, 13.....17, 21, 22,...., 27, 31, 32 - coded like  column*10 + row
    int pressedButtonID_ISR;  // the button number ranging from 0 to 20
    int flag_button_pressed = -1;     // to tell that a button was pressed
    int flag_button_pressed_ID = -1;     // to tell that a button was pressed - record the ID
    int flag_button_pressed_col = -1;     // to tell that a button was pressed - remind the colums
    int flag_button_pressed_row = -1;     // to tell that a button was pressed - remind the row

    // To record the 2 last pressed buttons simultaneously
    /*int last_pressed_col_1 = -1;
    int last_pressed_row_1 = -1;
    int last_pressed_col_2 = -1;
    int last_pressed_row_2 = -1;*/

    // Encoders management variables
     bool A_1_set = false;   
     bool B_1_set = false;
     bool A_2_set = false;   
     bool B_2_set = false;
     bool A_3_set = false;   
     bool B_3_set = false;
    
    int encoderPos_1 = 0;
    int encoderPos_2 = 0;
    int encoderPos_3 = 0;
    int old_encoderPos_1 = 0;
    int old_encoderPos_2 = 0;
    int old_encoderPos_3 = 0;

    // Buffer management
    unsigned long buffer_timer;
    int buffer_index = -1;
    bool flag_buffer = LOW;
    int buttonBits_buffer[25] =      {0, 0, 0, 0, 0, 0, 0, 0, 0, 0, 0, 0, 0, 0, 0, 0, 0, 0, 0, 0, 0, 0, 0, 0, 0};       // Button press buffer handling
    bool button_input_buffer[25]=    {0, 0, 0, 0, 0, 0, 0, 0, 0, 0, 0, 0, 0, 0, 0, 0, 0, 0, 0, 0, 0, 0, 0, 0, 0};      // Status of button press coming from input_management function

    // 7 segments
    uint8_t data[] = { 0xff, 0xff, 0xff, 0xff };
    int n = 0;
    unsigned long timeStamp1;

    unsigned long lastPrintMillis = 0;
    int selectedButtonByte = 2;   // button bytes are 3rd to 5th. initialize to 1st relevant byte.
    uint8_t incByte, prevPrintedByte, prevAlphaDisp[3];
    uint8_t isrIndex = 0;
    unsigned long delayMillis = 400; // wait at least the delay time since last spi communication before printing out whatever came in.

#ifdef HAS_TM1637
    TM1637Display display(TM1637_CLK_PIN, TM1637_DIO_PIN);
#endif

#ifdef HAS_NPX
    Adafruit_NeoPixel strip(NPX_NUMBER, NPX_PIN, NEO_GRB + NEO_KHZ800);
#endif

#ifdef HAS_OLED
    Adafruit_SSD1306 display2(SCREEN_WIDTH, SCREEN_HEIGHT, &Wire, OLED_RESET);
#endif


// Configure the Joystick for relevant platforms
#if defined(MICRO_WITH_HEADER) 
  // create joystick object
  Joystick_ Joystick(JOYSTICK_DEFAULT_REPORT_ID,JOYSTICK_TYPE_GAMEPAD,
  15, 0,                  // Button Count, Hat Switch Count
  false, false, false,     // X and Y, but no Z Axis
  false, false, false,   // No Rx, Ry, or Rz
  false, false,          // No rudder or throttle
  false, false, false);  // No accelerator, brake, or steering
#endif

#if defined(FULL_MICRO) 
  // create joystick object
  Joystick_ Joystick(JOYSTICK_DEFAULT_REPORT_ID,JOYSTICK_TYPE_GAMEPAD,
  32, 0,                  // Button Count, Hat Switch Count
  true, true, false,     // X and Y, but no Z Axis
  false, false, false,   // No Rx, Ry, or Rz
  false, false,          // No rudder or throttle
  false, false, false);  // No accelerator, brake, or steering
#endif

#if defined(BUTTON_BOX_PRO_MICRO) 
  // create joystick object
  Joystick_ Joystick(JOYSTICK_DEFAULT_REPORT_ID,JOYSTICK_TYPE_GAMEPAD,
  32, 0,                  // Button Count, Hat Switch Count
  true, true, false,     // X and Y, but no Z Axis
  false, false, false,   // No Rx, Ry, or Rz
  false, false,          // No rudder or throttle
  false, false, false);  // No accelerator, brake, or steerin
#endif
  
/////////////////////////////////////////////////////
// SETUP
void setup() {
  
  pinMode(MISO_PIN, OUTPUT);    // usually when using SPI, arduino will automatically define MISO as output, but not when doing SPI slave.
  pinMode(CLK_PIN, INPUT_PULLUP);
  pinMode(MOSI_PIN, INPUT_PULLUP);
  pinMode(INT_CS_SPI, INPUT_PULLUP);   // connecting CS_ISR pin (D2) to the SS pin (D10) is crucial. See the schematics.
  pinMode(CS_PIN, INPUT_PULLUP);     
  

  // Wheel configuration
  data_out.header = 0xa5;
  data_out.id = 0x0C;

  #ifdef AVR_BOARD
  // SPI initerrupts configuration for the arduino based boards
  attachInterrupt(digitalPinToInterrupt(INT_CS_SPI), cableselect, RISING);
  // SPCR BYTE should be: 11000100   note to self: by raw_capture.ino and fanatec.cpp spi settings, of btClubSportWheel by Darknao, SPI settings are SPI_Mode0 & MSBFIRST. but with logic scope I see that CPHA 1 (falling!) is used by wheel base, which means SPI_MODE1. (and MSBFIRST)
  // (Mode 1 - clock is normally low (CPOL = 0), and the data is sampled on the transition from high to low (trailing edge) (CPHA = 1))
  SPCR |= _BV(SPE);   // turn on SPI
  SPCR |= _BV(SPIE);    // turn on interrupts
  SPCR |= _BV(CPHA);    //turns on CPHA. as I found the CSW wheelbase to use it, with logic scope.
  #endif
  
  Serial.begin(230400);
  Serial.print("F_interface_AL - ");
  Serial.println(VERSION);
  Serial.println("Starting engine...");

  #if defined(FULL_NANO) || defined(FULL_NANO_ESP32) || defined(FULL_MICRO) || defined(BUTTON_BOX_PRO_MICRO)  // Define this for boards having an MCP23017
  // Initialize MCP23017 communication
  mcp.begin_I2C();
  mcp.setupInterrupts(true,false,LOW);
        // OPTIONAL - call this to override defaults
          // mirror INTA/B so only one wire required      @param mirroring true to OR both INTA and INTB pins.
          // active drive so INTA/B will not be floating  @param openDrain true for open drain output, false for active drive output.
          // INTA/B will be signaled with a LOW           @param polarity HIGH or LOW
  

  // configure pin for encoder inputs with pull up
  mcp.pinMode(ENC_1_A_PIN, INPUT_PULLUP);
  mcp.pinMode(ENC_1_B_PIN, INPUT_PULLUP);
  mcp.pinMode(ENC_2_A_PIN, INPUT_PULLUP);
  mcp.pinMode(ENC_2_B_PIN, INPUT_PULLUP);
  mcp.pinMode(ENC_3_A_PIN, INPUT_PULLUP);
  mcp.pinMode(ENC_3_B_PIN, INPUT_PULLUP);
  
  // enable interrupt on each required pins
  mcp.setupInterruptPin(ENC_1_A_PIN, CHANGE);
  mcp.setupInterruptPin(ENC_1_B_PIN, CHANGE);
  mcp.setupInterruptPin(ENC_2_A_PIN, CHANGE);
  mcp.setupInterruptPin(ENC_2_B_PIN, CHANGE);
  mcp.setupInterruptPin(ENC_3_A_PIN, CHANGE);
  mcp.setupInterruptPin(ENC_3_B_PIN, CHANGE);

  mcp.setupInterruptPin(BMATRIX_ROW1, CHANGE);
  mcp.setupInterruptPin(BMATRIX_ROW2, CHANGE);
  mcp.setupInterruptPin(BMATRIX_ROW3, CHANGE);
  mcp.setupInterruptPin(BMATRIX_ROW4, CHANGE);
  mcp.setupInterruptPin(BMATRIX_ROW5, CHANGE);
  mcp.setupInterruptPin(BMATRIX_ROW6, CHANGE);
  mcp.setupInterruptPin(BMATRIX_ROW7, CHANGE);

  pinMode(INTERRUPT_PIN, INPUT);      // No need of the pullup as the MCP23017 will have an active drain output.
  attachInterrupt(digitalPinToInterrupt(INTERRUPT_PIN), ISR_MCP, CHANGE);
  #endif

  #if defined(MICRO_WITH_HEADER) || defined(ATMEGA328P_WITH_HEADER) || defined(NANO_WITH_HEADER)
    pinMode(BUT_1_PIN, INPUT_PULLUP);
    pinMode(BUT_2_PIN, INPUT_PULLUP);
    pinMode(BUT_3_PIN, INPUT_PULLUP);
    pinMode(BUT_4_PIN, INPUT_PULLUP);
    pinMode(BUT_5_PIN, INPUT_PULLUP);
    pinMode(BUT_6_PIN, INPUT_PULLUP);
    pinMode(BUT_7_PIN, INPUT_PULLUP);
    pinMode(BUT_8_PIN, INPUT_PULLUP);
    pinMode(BUT_9_PIN, INPUT_PULLUP);
    pinMode(BUT_10_PIN, INPUT_PULLUP);
    pinMode(BUT_11_PIN, INPUT_PULLUP);
    pinMode(BUT_12_PIN, INPUT_PULLUP);
    pinMode(BUT_13_PIN, INPUT_PULLUP);
    pinMode(BUT_14_PIN, INPUT_PULLUP);
    pinMode(BUT_15_PIN, INPUT_PULLUP);
  #endif  

  #if defined(BUTTON_BOX_PRO_MICRO)
    pinMode(FUNKY_PUSH, INPUT_PULLUP);
    pinMode(BUT_1_PIN, INPUT_PULLUP);
    pinMode(BUT_2_PIN, INPUT_PULLUP);
    pinMode(BUT_3_PIN, INPUT_PULLUP);
    pinMode(BUT_4_PIN, INPUT_PULLUP);
    pinMode(BUT_5_PIN, INPUT_PULLUP);
    pinMode(BUT_6_PIN, INPUT_PULLUP);
  #endif

  #ifdef  HAS_BUTTON_MATRIX
      
      set_MCP_listenning_BMX();     // Configure MCP inputs and outputs to detect a button press and trigger interrupt

      // Setup button matrix
      /*for (int x = 0; x < BMATRIX_ROWS; x++) {
          mcp.pinMode(BMATRIX_ROWSDEF[x], INPUT);
      }
      for (int x = 0; x < BMATRIX_COLS; x++) {
          mcp.pinMode(BMATRIX_COLSDEF[x], INPUT_PULLUP);
      }*/
  #endif
  
  #ifdef HAS_NPX
    strip.begin();           // INITIALIZE NeoPixel strip object (REQUIRED)
    strip.show();            // Turn OFF all pixels ASAP
    strip.setBrightness(50); // Set BRIGHTNESS to about 1/5 (max = 255)

    play_init_rev_LEDs();   // Plays initialization animation
  #endif 

  #ifdef HAS_OLED
    // SSD1306_SWITCHCAPVCC = generate display voltage from 3.3V internally
    if(!display2.begin(SSD1306_SWITCHCAPVCC, SCREEN_ADDRESS)) {
      Serial.println(F("SSD1306 allocation failed"));
      for(;;); // Don't proceed, loop forever
    }
    display2.display();
    display2.setTextSize(1);              // Normal 1:1 pixel scale
    display2.setTextColor(SSD1306_WHITE); // Draw white text
      
  #endif

  // Configure the Joystick for relevant platforms
  #if defined(MICRO_WITH_HEADER) 
    Joystick.begin();   
  #endif

  #if defined(FULL_MICRO) 
    Joystick.begin();
    Joystick.setXAxisRange(0, MAX_ADC);
    Joystick.setYAxisRange(0, MAX_ADC);
  #endif
  
  #if defined(BUTTON_BOX_PRO_MICRO) 
    Joystick.begin();
    Joystick.setXAxisRange(0, MAX_ADC);
    Joystick.setYAxisRange(0, MAX_ADC);
  #endif
  
  Serial.println("Starting the race !...");
}

void loop() {

  calcOutgoingCrc();
  //yield_F();
  
  crc8Stat = checkIncomingCrc();
  yield_F();
  
  // For debug purposes : 
  // printmosibuf();         // prints data sent from the base to the wheel
  // printmisobuf();         // prints data sent from the wheel to the base
  if (BUTTON_DEBUG == 1) {
    if (millis() - tempo > 200) {
      // serialOutput();           // Prints I/O state to Serial Output
      tempo = millis();  
    }
  }

  // For test purposes
  //test_output();
  //test_leds();
  //test_7segments();
  
  yield_F();             // Handles the interrupt ISR results asynchroneously in the main loop
  
  //Handles inputs and outputs for PCBS having some, skip for others
  #if defined(FULL_NANO) || defined(FULL_NANO_ESP32) || defined(FULL_MICRO) || defined(BUTTON_BOX_PRO_MICRO) || defined(MICRO_WITH_HEADER) || defined(ATMEGA328P_WITH_HEADER) || defined(NANO_WITH_HEADER)
    inputs_management();      // handles button presses, rotary switches,....
    //yield_F();
    buttonBit_buffer_handling();  

    #ifdef HAS_TM1637
        update_7_segments();
        yield_F();
    #endif

    #ifdef HAS_NPX
        update_rev_LEDS();
        yield_F();
    #endif
  #endif
  yield_F();
}

void ISR_MCP() {
  flag_ISR = 1;
}
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

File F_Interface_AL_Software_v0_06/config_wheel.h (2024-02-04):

#ifndef config_w_h
#define config_w_h

/* This file can help you configure your wheel
  You can select which Input / outputs you want to use and to which buttons in Fanatec interface you want to associate them.

  To better understand how the wheel communicates with the base, please read the Fanatec_data_structure.h file.

  Configure the inputs / output - comment them out do deactivate them
*/


#define VERSION "0.06.01"

/////////////////////////////////
// TYPE OF PCB //
/////////////////////////////////
// #define ATMEGA328P_NO_HEADER    //  PCB version with only the ATMEGA 328P to unlock the FOrce Feedback - runs at 3,3V
// #define ATMEGA328P_WITH_HEADER  //  PCB version with the ATMEGA 328P to unlock the Force Feedback and headers around the board to connect a few buttons - runs at 3,3V
// #define NANO_NO_HEADER          //  PCB version with only the Arduino nano to unlock the FOrce Feedback - runs at 5V, needs a stepup voltage regulator
// #define NANO_WITH_HEADER        //  PCB version with the Arduino nano to unlock the FOrce Feedback and headers around the board to connect a few buttons - runs at 5V, needs a stepup voltage regulator
// #define MICRO_WITH_HEADER       //  PCB version with the Arduino PRO MICRO to unlock the FOrce Feedback and headers around the board to connect a few buttons + Joystick possibility - runs at 5V, needs a stepup voltage regulator
#define FULL_NANO               //  PCB version with the Arduino nano and the MCP23017 to have a lot of option to connect buttons, rotary encoder and rotary switches - runs at 5V, needs a stepup voltage regulator
//#define FULL_NANO_ESP32         //  PCB version with the Arduino nano ESP32 and the MCP23017 to have a lot of option to connect buttons, rotary encoder and rotary switches + LCD diplay possiblity- runs at 3,3V
//  #define FULL_MICRO               //  PCB version with the Arduino PRO MICRO and the MCP23017 to have a lot of option to connect buttons, rotary encoder and rotary switches + Joystick possiblity- runs at 5V, needs a stepup voltage regulator
// #define BUTTON_BOX_PRO_MICRO  //  PCB version with the Arduino PRO MICRO and the MCP23017 to have a lot of option to connect buttons, rotary encoder and rotary switches + Joystick possiblity to build a button box - runs at 5V, needs a stepup voltage regulator


#define BUTTON_DEBUG 1           // Displays live button output on Serial port for debug purposes
#define ANALOG_SAMPLES 3         // Number of analog smaple to average for each reading.
#define ECART_RS 30              // Threshold used to declare a RS measurement stable so that is can be processed.
#define DEBOUNCE_DELAY 10        // Debounce delay - minimum delay between 2 button presses
#define TEMPORARY_PRESS_TIME 30  // Duration of a temporary button press for impulsion based inputs (like rotary encoders and rotary switches)

#if defined(FULL_NANO_ESP32)  // Define this for boards having a 12 bits ADC
#define MAX_ADC 4096          // MAx value of ADC - ESP is 12 bits : 4095, ESP32 based boards are 12 bits : 4095
#else
#define MAX_ADC 1023  // MAx value of ADC - Arduino nano & micro are 10 bits : 1023, ESP32 based boards are 12 bits : 4095
#endif

//////////////////////////////////////////////////////////////////////////////////////////////////////
//      GENERAL CONFIGURATION                                                                       //
//////////////////////////////////////////////////////////////////////////////////////////////////////

#define HAS_BUTTON_MATRIX  // Activates button matrix that has a 3x7 size

//#define HAS_DPAD                // Activated Dpad buttons
// #define HAS_FUNKY                // Activated FUNKY switch buttons - center press not functionnal

// #define HAS_RS_1                // Activates rotary switch 1 + buttonbits assignment
//#define HAS_RS_2  // Activates rotary switch 1 + buttonbits assignment
//#define HAS_RS_3  // Activates rotary switch 1 + buttonbits assignment
// #define HAS_RS_4                // Activates rotary switch 1 + buttonbits assignment

// #define HAS_ANALOG_AXIS         // Activates the analog readings of axis X and Y

#define HAS_ENC_1  // Activates Encoder 1 + buttonbits assignment
//  #define HAS_ENC_2  // Activates Encoder 2 + buttonbits assignment
// #define HAS_ENC_3  // Activates Encoder 3 + buttonbits assignment
// 
// #define HAS_NPX                 // Activates Neopixels
// #define HAS_TM1637              // Activates TM1637 7 segments display
// #define HAS_OLED                // Activates OLED Display
// #defc fine HAS_TFT                 // Activates LCD TFT Display // Not coded yet.

// SEE BELOW FOR FURTHER CONFIGURATION OPTIONS FOR EACH INPUT

/*  Button bits mapping for Fanatec wheel

Some button bits à reserved in Fanatec SPI communicaiton protocol, here are advice based on Darknao / Ishachar work and my experience
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

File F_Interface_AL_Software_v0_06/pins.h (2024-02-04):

#ifndef PIN_H
#define PIN_H

#include "config_wheel.h" 

#define AVR_BOARD
#ifdef AVR_BOARD

  #ifdef FULL_NANO
    // NEW PINOUT
    #define INTERRUPT_PIN       3     // Pin D3 of arduino nano - equivalent to GPIO 6- interrupt signal coming from MCP23017
    #define INT_CS_SPI          2     // D2
    #define LCD_CS_PIN          5     // D5
    #define LCD_RS_PIN          6     // D6
    #define BUT_1_PIN           7     // D7
    #define BUT_2_PIN           8     // D8
    #define NPX_PIN             9     // D9
    #define CS_PIN              10    // D10
    #define MOSI_PIN            11    // D11
    #define MISO_PIN            12    // D12
    #define CLK_PIN             13    // D13
    #define FUNKY_A_PIN         A7    // A7
    #define DPAD_PIN            A7    // A7
    #define RS_1_PIN            A0    // A0
    #define RS_2_PIN            A1    // A1
    #define RS_3_PIN            A2    // A2
    #define RS_4_PIN            A3    // A3
    // A4 - I2C - SDA
    // A5 - I2C - SCL
    #define AXIS_X_PIN          A3    // A3
    #define AXIS_Y_PIN          A6    // A6
  #endif

#ifdef FULL_MICRO
    #define INTERRUPT_PIN       0     // Pin D3 of arduino nano - equivalent to GPIO 6- interrupt signal coming from MCP23017
    #define INT_CS_SPI          7     // D2
    #define LCD_CS_PIN          5     // D5
    #define LCD_RS_PIN          6     // D6
    #define BUT_1_PIN           A0  
    #define BUT_2_PIN           A1   
    #define BUT_3_PIN           1  
    #define BUT_4_PIN           5   
    #define NPX_PIN             A2   
    #define CS_PIN              7 
    #define MOSI_PIN            16
    #define MISO_PIN            14
    #define CLK_PIN             15
    #define FUNKY_A_PIN         A3   
    #define DPAD_PIN            A3   
    #define RS_1_PIN            A6    
    #define RS_2_PIN            A7   
    #define RS_3_PIN            A8
    #define RS_4_PIN            A9  
    // A4 - I2C - SDA
    // A5 - I2C - SCL
    #define AXIS_X_PIN          A9    // A3
    #define AXIS_Y_PIN          A10    // A6
  #endif

#ifdef BUTTON_BOX_PRO_MICRO
    #define INTERRUPT_PIN       0     // Pin D3 of arduino nano - equivalent to GPIO 6- interrupt signal coming from MCP23017
    #define INT_CS_SPI          2     // D2
    #define LCD_CS_PIN          5     // D5
    #define LCD_RS_PIN          6     // D6
    #define BUT_1_PIN           A1  
    #define BUT_2_PIN           A0   
    #define BUT_3_PIN           15  
    #define BUT_4_PIN           14   
    #define BUT_5_PIN           16  
    #define BUT_6_PIN           7   
    #define NPX_PIN             A2   
    #define CS_PIN              7 
    #define MOSI_PIN            16
    #define MISO_PIN            14
    #define CLK_PIN             15
    #define FUNKY_A_PIN         A3   
    #define FUNKY_PUSH          1  
    #define DPAD_PIN            A3   
    #define RS_1_PIN            6    
    #define RS_2_PIN            4   
    #define RS_3_PIN            4
    #define RS_4_PIN            A9   
    // A4 - I2C - SDA
    // A5 - I2C - SCL
    #define AXIS_X_PIN          9    // A3
    #define AXIS_Y_PIN          10    // A6
  #endif

  #if defined(NANO_NO_HEADER) || defined(NANO_WITH_HEADER)  || defined(ATMEGA328P_NO_HEADER)  || defined(ATMEGA328P_WITH_HEADER) 
    #define INTERRUPT_PIN       3     // Pin D3 of arduino nano - equivalent to GPIO 6- interrupt signal coming from MCP23017
    #define INT_CS_SPI          2     // D2
    #define BUT_1_PIN           0    
    #define BUT_2_PIN           1    
    #define BUT_3_PIN           3    
    #define BUT_4_PIN           4    
    #define BUT_5_PIN           5    
    #define BUT_6_PIN           6    
    #define BUT_7_PIN           7     
    #define BUT_8_PIN           8     
    #define BUT_9_PIN           9     
    #define BUT_10_PIN          A0    
    #define BUT_11_PIN          A1    
    #define BUT_12_PIN          A2    
    #define BUT_13_PIN          A3    
    #define BUT_14_PIN          A4    
    #define BUT_15_PIN          A5    
    #define NPX_PIN             9     // D9
    #define CS_PIN              10    // D10
    #define MOSI_PIN            11    // D11
    #define MISO_PIN            12    // D12
    #define CLK_PIN             13    // D13
    #define FUNKY_A_PIN         A7    // A7
    #define DPAD_PIN            A7    // A7
    #define RS_1_PIN            A0    // A0
    #define RS_2_PIN            A1    // A1
    #define RS_3_PIN            A2    // A2
    #define RS_4_PIN            A3    // A3
    // A4 - I2C - SDA
    // A5 - I2C - SCL
    #define AXIS_X_PIN          A3    // A3
    #define AXIS_Y_PIN          A6    // A6
  #endif
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

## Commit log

2023-07-19 Add files via upload
    Initial commit
    [F_INTERFACE_AL_vM_0.01.fzz, F_Interface_AL_Hardware_v0.01.fzz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]
2023-08-18 Add files via upload
    DIY Steering Wheel
    AL
    2/6/23
    v0.02 changelog :
    - capacitors labels pF --> nF
    - Sensors holes changed to medium size
    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
    [F_Interface_AL_Hardware_v0.02.fzz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]
2023-08-25 Update README.md
    Updated ICSP flash instruction link : https://docs.arduino.cc/built-in-examples/arduino-isp/ArduinoISP
2023-09-21 Add files via upload
    Bugs solved :
    - Rotary switches debounce
    - Conflict between press buttons and impulsion based buttons when they point to the same button bit
    [F_Interface_AL_Software_v0.01.ino, Pins.h, config_wheel.h]
2023-09-21 Update README.md
    Added photos of PCB
2023-09-28 Update README.md
    UPDATED GENERAL schematic
2023-10-20 Add files via upload
    Fixed issue with 7 segment display and parse + check LEDS are working fine
    [F_Interface_AL_Software_v0.01.ino, Pins.h, config_wheel.h]
2023-10-20 Add files via upload
    Added old files for records
    [F_INTERFACE_AL_vM_0.01.fzz]
2023-10-20 Add files via upload
    Move from v0.01 to v0.02 as it's now stable and usable
    [7 segments BIN ASCII lookup table.xlsx]
2023-10-20 Delete F_Interface_AL_Software_v0.01 directory
    Move to v0.02 - will be archived in OLD_VERSIONS
    [7 segments BIN ASCII lookup table.xlsx]
2023-10-20 Add files via upload
    Added old versions for the records
    [7 segments BIN ASCII lookup table.xlsx]
2024-04-17 Add files via upload
    FIxed issue with CRC8stat variable declaration, moved from loop to global variable + added pins for TM1637 support on arduino nano full and pro micro full versions
    [F_Interface_AL_Software_v0_06.ino]

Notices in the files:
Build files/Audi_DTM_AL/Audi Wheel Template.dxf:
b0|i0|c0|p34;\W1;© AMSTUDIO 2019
